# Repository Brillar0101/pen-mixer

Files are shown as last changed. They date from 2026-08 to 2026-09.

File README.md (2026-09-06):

# Pen Mixer

Pen Mixer is a small motion controller that clips onto the top of an ordinary
pen and turns handwriting gestures into live audio control. An IMU on the
board reads tilt and twist, an nRF52840 sends the motion to a laptop over
Bluetooth, and the laptop shapes whatever track is playing: tilt the pen and
a filter sweeps, twist it and the level moves. The better your pen control
gets, the better your mix sounds.

<p align="center">
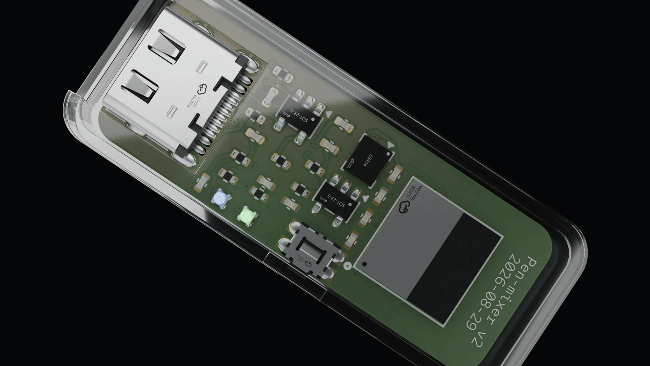
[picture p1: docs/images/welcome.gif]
Pen Mixer v2.1 in its clear case, from five angles
  
</p>

<p align="center"><em>The v2.1 board (13 &times; 35 mm) in its clear case</em></p>

This repo holds the whole project: prototype firmware, production firmware and
laptop stack, and the production PCB as a KiCad project.

```mermaid
flowchart LR
    HAND["Hand<br>tilt, twist"] --> FW

    subgraph pen["Pen Mixer board: on the pen"]
        FW["LSM6DS3TR-C IMU<br>+ ISP1807 nRF52840"]
    end

    FW -->|"BLE, Nordic UART"| BR
    FW -.->|"USB-C, serial"| BR

    subgraph laptop["Laptop"]
        BR["bridge.py<br>smooth, map"] -->|"UDP"| PD["Pure Data<br>filter + gain"]
        BR -->|"SSE"| DASH["dashboard<br>localhost:8080"]
    end

    PD --> SPK["Speakers"]

    classDef pfBlue fill:#E7F1FA,stroke:#0066CC,color:#151515
    classDef pfGold fill:#FDF7E7,stroke:#F0AB00,color:#151515
    classDef pfGreen fill:#F3FAF2,stroke:#3E8635,color:#151515
    classDef pfGray fill:#F0F0F0,stroke:#6A6E73,color:#151515
    class HAND,SPK pfBlue
    class FW pfGreen
    class BR pfGold
    class PD,DASH pfGray
```

## The hardware

Two production board shapes exist. v2.1 is a 13 x 35 mm bar (frozen in
`production/kicad/v2/`). v3, the current design in `production/kicad/`, is a
regular five-point star 40 mm tip to tip with a vertical, top-entry USB-C
(G-Switch GT-USB-7055E) in the body so all five prongs are identical, the
antenna at the top tip, LEDs out on the left arm and the button in the right
arm; otherwise the same parts and the same four-layer 0.8 mm stack. The v2.1 board is a 13 x 35 mm, four-layer, 0.8 mm PCB, all SMD, designed
to ride on a pen barrel with a 401230 LiPo at the back of the pen.

| Ref | Part | Role |
|---|---|---|
| U1 | ISP1807 | nRF52840 with integrated antenna, pre-certified |
| U2 | LSM6DS3TR-C | 6-axis IMU |
| U3 | MCP73831 | LiPo charger, 50 mA |
| U4 | TPS7A02 | 3.3 V LDO, 200 nA quiescent |
| J1 | USB-C 16P | charge, programming, serial |
| J2 | pads on B.Cu | off-board LiPo, 401230 |

The KiCad project lives in `production/`. Schematic PDF, board plots, a render
and the BOM are in `production/output/`.

The board is fully routed and fabrication-ready: 0 unrouted connections,
ground pours on all four layers, and a clean DRC. U1 sits on the official
JLCPCB land pattern with part-for-part verified pad geometry, and every
component carries the 3D model of the exact part being ordered.

Every pinout came from a primary datasheet, kept in `production/datasheets/`.
The one that would have cost a board spin: ISP1807 pin 20 (OUT_ANT) must be
tied to pin 22 (OUT_MOD) on the application PCB, or the radio has no antenna.

## The firmware and laptop stack

`prototype/` runs on the Seeed XIAO nRF52840 Sense today and targets the
custom board unchanged, since both are an nRF52840 with an ST IMU on I2C.

```
prototype/
  bridge.py           serial or BLE, then smoothing, mapping, UDP, dashboard
  ble_source.py       laptop-side BLE client for --ble
  dashboard.py        live web view on :8080
  firmware/
    code.py           IMU over USB serial
    code_ble.py       IMU over BLE, advertises as PenMixer-Lexy
  patches/            Pure Data: track playback, manual sliders, live input
```

How to run all of it, from firmware to Pure Data to the dashboard, lives in
[docs/RUNNING.md](docs/RUNNING.md).

## Run the desktop app

The Qt app in `app/` is the laptop side: it EQs whatever the computer is
playing, driven by the pen over Bluetooth. Full detail, Docker, and
troubleshooting are in `app/README.md`; the short version:

### macOS

```bash
brew install blackhole-2ch switchaudio-osx       # first time only
git clone https://github.com/Brillar0101/pen-mixer.git
cd pen-mixer/app
python3 -m venv venv
venv/bin/pip install -r requirements.txt -e .    # first time only
venv/bin/python -m penmixer.app                  # every time
```

In the window: click "Route system audio here", set Source to "Bluetooth
(pen board)" or use "Scan Bluetooth", play music, move the pen. Closing the
app restores your speakers.

### Windows

First time only, in an administrator PowerShell, then reboot (VB-CABLE is
the Windows loopback device):

```powershell
curl.exe -L -o $env:TEMP\vbcable.zip https://download.vb-audio.com/Download_CABLE/VBCABLE_Driver_Pack45.zip
Expand-Archive $env:TEMP\vbcable.zip $env:TEMP\vbcable -Force
& $env:TEMP\vbcable\VBCABLE_Setup_x64.exe
shutdown /r /t 0
```

Then in a normal PowerShell:

```powershell
git clone https://github.com/Brillar0101/pen-mixer.git
cd pen-mixer\app
python -m venv venv
venv\Scripts\pip install -r requirements.txt -e .   # first time only
venv\Scripts\python -m penmixer.app                 # every time
```

Set Settings > System > Sound > Output to "CABLE Input", then in the window
click "Hear music here", set Source to "Bluetooth (pen board)", play music,
move the pen. Set the output back to your speakers when done.

No board? Set Source to "Simulate (no board)".

## Measured, not estimated

| What | Number |
|---|---|
| Frame rate over USB | 197 Hz against a 250 Hz target |
| Frames in the soak run | 105,872, 0 malformed |
| Smoother settling, alpha 0.4 | 24 ms to 95% of a step |
| End-to-end budget | 32 ms, against ~20 ms where feel degrades |
| BLE vs USB link cost | ~10 ms vs 1 ms |

## Layout

```
prototype/            nRF52840 Sense build: real IMU, USB or BLE, laptop stack
app/                  Qt desktop app: 3-band EQ, visualizer, one-window stack
                      (start instructions for macOS and Windows: app/README.md)
production/           the production board
  kicad/              KiCad 10 project, footprints, 3D models
  datasheets/         primary sources for every pinout
  output/             schematic PDF, board plots, render, BOM, DRC report
docs/                 architecture, run guide, requirements (PRD)
ARCHITECTURE.md       how it all fits together, with diagrams
```

## License

MIT. See [LICENSE](LICENSE).

Built by Barakaeli ([Brillar0101](https://github.com/Brillar0101)) and
Lexy ([vnllagoldfish](https://github.com/vnllagoldfish)).

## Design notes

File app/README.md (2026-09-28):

# Pen Mixer EQ (Qt)

Move a pen, shape the music. This app turns motion from the Pen Mixer board
into a live three-band EQ over whatever the computer is playing: tilt the
pen and the bass swells, roll it and the treble lifts, do both and the mids
come up. A spectrum visualizer and waveform show the sound changing in real
time.

This README explains the whole project from zero: where it came from, how
every piece works, how to run it, and every problem we hit along the way so
you do not have to rediscover them.

## Quick start

Everything below assumes the pen board is already flashed (see
`prototype/flash/README.md`) and advertising as "PenMixer-Lexy".

### macOS

First time only:

```bash
brew install blackhole-2ch switchaudio-osx
git clone https://github.com/Brillar0101/pen-mixer.git
cd pen-mixer/app
python3 -m venv venv
venv/bin/pip install -r requirements.txt -e .
```

Every time:

```bash
cd pen-mixer/app
venv/bin/python -m penmixer.app
```

In the window: click "Route system audio here" (music now flows through the
app), set Source to "Bluetooth (pen board)" or click "Scan Bluetooth" and
pick PenMixer-Lexy, play music, move the pen. Allow the Bluetooth permission
prompt the first time. Closing the app hands your speakers back.

### Windows

First time only (VB-CABLE is the Windows loopback; details in "Running it
on Windows" below):

```powershell
# administrator PowerShell, then reboot
curl.exe -L -o $env:TEMP\vbcable.zip https://download.vb-audio.com/Download_CABLE/VBCABLE_Driver_Pack45.zip
Expand-Archive $env:TEMP\vbcable.zip $env:TEMP\vbcable -Force
& $env:TEMP\vbcable\VBCABLE_Setup_x64.exe
shutdown /r /t 0
```

```powershell
# normal PowerShell, after the reboot
git clone https://github.com/Brillar0101/pen-mixer.git
cd pen-mixer\app
python -m venv venv
venv\Scripts\pip install -r requirements.txt -e .
```

Every time:

```powershell
cd pen-mixer\app
venv\Scripts\python -m penmixer.app
```

Set Windows Settings > System > Sound > Output to "CABLE Input", then in the
window click "Hear music here", set Source to "Bluetooth (pen board)" or use
"Scan Bluetooth", play music, move the pen. Set the Windows output back to
your speakers when you are done.

### No board handy

Set Source to "Simulate (no board)": synthetic pen motion sweeps all three
bands so the whole pipeline demos untethered.

### Spotify now playing, optional

The track card and transport buttons read Spotify's Web API. Without the
setup below the app runs normally with that panel disabled.

1. Create an app at developer.spotify.com/dashboard. Under Redirect URIs
   add exactly `http://127.0.0.1:8888/callback` (Spotify no longer accepts
   `localhost`). Copy the Client ID; there is no secret to keep, the app
   uses PKCE.
2. Put the Client ID in the environment of the shell that launches the app.

   macOS:

   ```bash
   export SPOTIFY_CLIENT_ID=your-client-id
   venv/bin/python -m penmixer.app
   ```

   Windows, this window only:

   ```powershell
   $env:SPOTIFY_CLIENT_ID = "your-client-id"
   venv\Scripts\python -m penmixer.app
   ```

   Windows, permanently (then open a new terminal):

   ```powershell
   setx SPOTIFY_CLIENT_ID "your-client-id"
   ```

3. The first launch opens a browser for the Spotify login. After that the
   token is cached at `~/.cache/penmixer/spotify_token.json` and sign-in is
   silent.

Reading what is playing works on any account; play, pause and skip call
endpoints Spotify limits to Premium. This only feeds the panel and the
buttons: the audio the EQ shapes still has to arrive through BlackHole or
VB-CABLE.

## Where this fits in the bigger project

The parent project is the Pen Mixer: a tiny board (nRF52840 + IMU) that clips
onto a pen and turns handwriting gestures into audio control over Bluetooth.
That hardware lives in this repo (`production/` for the board,
`prototype/firmware/` for the firmware), and its product requirements call
for a three-band EQ mapped to pen motion (bass 60-250 Hz, mid 250 Hz-2 kHz,
treble 2-20 kHz).

During prototyping the board is a Seeed XIAO nRF52840 Sense running the same
firmware. This directory is the laptop side: one Qt app that replaced the
previous three-piece stack (a serial bridge script, a browser dashboard, and
Pure Data patches) with a single window that owns everything. That was a
deliberate requirement: the Qt interface is the only source of truth. Serial
reading, audio processing, and the UI all live in this one process, so what
you see is always what is actually happening.

## How it works, end to end

Follow one pen move through the system:

1. The board runs `code.py` (CircuitPython, in `../prototype/firmware/`).
   Its 6-axis IMU reads tilt and roll from gravity, so 0.0 means the pen is
   level and the ends of the range mean a full lean.

2. Every ~6 ms the firmware prints one line over USB serial:
   `tilt,roll,energy`. Tilt spans -45 to +45 degrees, roll -90 to +90, and
   energy 0 to 1 for overall motion. The BLE firmware emits the same frame
   format over the air, which is the point: everything downstream works
   unchanged whichever link carries it.

3. `serialio.py` runs a Qt thread that auto-discovers the board's port
   (`/dev/cu.usbmodem*`), parses frames (`frames.py`), and reconnects by
   itself if the board is unplugged. A banner at the top of the window shows
   the board state at all times: red "Pen board not detected", green
   "Pen board connected on <port>", amber "simulated input". The banner is
   separate from the audio status line so the two never overwrite each other.

4. `mapping.py` converts a frame to gains, deliberately simple and
   deterministic: tilt scales a bass boost from 0 to +12 dB, roll the same
   for treble, and the mids follow the weaker of the two, so moving both
   ways at once raises the middle. At rest always means flat, 0 dB; the
   music is unchanged until the pen moves. A one-pole smoother tuned to
   ~24 ms (the PRD's F2 figure) keeps the motion glide-smooth.

5. The gains drive three RBJ biquad filters in `eqdsp.py`: a low shelf at
   250 Hz, a peaking filter at 700 Hz (the geometric center of the PRD's mid
   band), and a high shelf at 2 kHz. Filter state persists across blocks;
   coefficients are recomputed only when a gain actually changes, and the
   audio callback ramps toward targets so there are never clicks.

6. `audio.py` owns a duplex sounddevice stream: it reads the system's music
   from the BlackHole loopback device, runs it through the EQ, and writes it
   to the real speakers or headphones. It also applies -9 dB of input
   headroom, because BlackHole delivers system audio hotter than full scale
   (we measured peaks of 1.6) and a +12 dB boost on top of that would clip.

7. `spectrum.py` runs numpy's rfft over the last 2048 output samples and
   produces both three band levels and 32 log-spaced bars (50 Hz to 16 kHz,
   dB scale). `viz.py` draws them cava-style, colored by band, with the raw
   waveform drawn behind. The bars analyze the processed signal, the same
   samples going to your ears, so what you see is real: boost the bass and
   the blue bars rise because the audio itself changed. Only the motion
   styling (fast rise, smooth decay, held peak caps) is cosmetic.

8. `ui.py` is the single source of truth: the window owns the reader, the
   engine, and the gain state. Motion drives the sliders and the sliders
   drive the DSP; untick "Pen control" and you can drag the sliders by
   hand (including cuts). Live meters show the raw tilt and roll input as
   it moves.

## Why BlackHole, and how the routing works

macOS gives no direct way to process another app's audio. The standard
answer is a loopback device: BlackHole 2ch is a virtual audio device that
acts like a cable. Route the system's output into it, and whatever any app
plays lands there as an input this app can read. The chain during a session:

```
YouTube/Spotify -> BlackHole 2ch -> this app (EQ + visualizer) -> speakers
```

Doing that by hand means fiddling with Sound settings, so the app does it
with one click. The "Route system audio here" button (using the
SwitchAudioSource CLI) switches the system output to BlackHole, selects your
real speakers or headphones as the app's output, and starts the engine
immediately, so the music never goes silent, it just changes path. Stopping
the audio or closing the app restores the previous output automatically.
BlackHole itself is excluded from the output choices because selecting it
would create a silent loop.

## Running it

Prerequisites on macOS: `brew install blackhole-2ch` for the loopback and
optionally `brew install switchaudio-osx` for the one-click routing button.

```bash
git clone https://github.com/Brillar0101/pen-mixer.git
cd pen-mixer/app
python3 -m venv venv
venv/bin/pip install -r requirements.txt -e .
venv/bin/python -m penmixer.app
```

Then, in the window:

1. Click "Route system audio here" and play music anywhere
2. Waves and spectrum bars move; you hear the music through the app
3. Set Source to "Bluetooth (pen board)", or click "Scan Bluetooth" and pick
   PenMixer-Lexy; the banner turns green when connected
4. Tilt for bass, sway sideways for mids, twist for treble; each gesture
   boosts one way and cuts the other, and the pen at rest leaves the music flat

No board? Set Source to "Simulate (no board)" and synthetic motion sweeps
the controls so the whole pipeline demos untethered.

## Running it on Windows

The app is cross-platform Python; only the loopback device and the routing
button differ from macOS.

1. Install Python 3.11+ from python.org (tick "Add python.exe to PATH").
   If `python` opens the Microsoft Store instead of running, use `py` in the
   commands below, or reinstall with the PATH box ticked.
2. Install the loopback device: VB-Audio Virtual Cable, the Windows
   equivalent of BlackHole. In an administrator PowerShell (right-click
   Start > Terminal (Admin)):

```powershell
curl.exe -L -o $env:TEMP\vbcable.zip https://download.vb-audio.com/Download_CABLE/VBCABLE_Driver_Pack45.zip
Expand-Archive $env:TEMP\vbcable.zip $env:TEMP\vbcable -Force
& $env:TEMP\vbcable\VBCABLE_Setup_x64.exe    # click "Install Driver"
shutdown /r /t 0                              # reboot is mandatory
```

   If the download URL fails, get it from vb-audio.com/Cable instead:
   extract, right-click `VBCABLE_Setup_x64.exe`, Run as administrator,
   Install Driver, reboot. After the reboot, verify the cable exists:

```powershell
venv\Scripts\python -c "import sounddevice; print(sounddevice.query_devices())"
```

   The list must show "CABLE Input (VB-Audio Virtual Cable)" and "CABLE
   Output (VB-Audio Virtual Cable)". No CABLE devices means the install or
   the reboot did not happen. If they are in the list but not in the app,
   click the app's Rescan button.
3. Clone and set up (run from the project root, and keep the trailing dot
   on the install command; it means "this folder" and installs the app):

```powershell
git clone https://github.com/Brillar0101/pen-mixer.git
cd pen-mixer\app
python -m venv venv
venv\Scripts\pip install -r requirements.txt -e .
venv\Scripts\python -m penmixer.app
```

4. Route the audio by hand (the route button is macOS-only, it uses a
   macOS tool): Settings > System > Sound > Output > "CABLE Input
   (VB-Audio Virtual Cable)". Then click "Hear music here" in the app: it
   selects CABLE Output as input, your speakers as output, and starts the
   audio, trying several sample rates until the stream opens. The music
   becomes audible through the app, with the EQ live on it.
5. Plug in the board. Windows names serial ports COM3-style and the app
   accepts any COM port that reports a USB vendor id, so detection works
   the same; the banner turns green.

Remember to switch the system output back to your speakers when done;
on Windows the app cannot restore it for you.

Do not use "Stereo Mix" as the input even though it looks like a loopback:
it taps the same speakers this app plays into, so the app would hear its
own output and feed back on itself, and many Realtek drivers mix the
microphone into it as well.

## Spotify now playing

The track card (artwork, title, artist, progress) and the transport buttons
talk to the Spotify Web API. This is separate from the audio path: the API
tells the app what is playing, while the sound itself still has to reach the
EQ through the loopback device. Fixing one does not fix the other, and the
EQ works fine with Spotify never configured at all.

Auth is PKCE, so there is no client secret to keep safe, but you do need a
client id of your own. It is not a secret and it is safe to paste into a
shell.

1. Go to https://developer.spotify.com/dashboard and create an app. Any name
   works.
2. In the app's settings, add `http://127.0.0.1:8888/callback` as a redirect
   URI. It has to match exactly, including the port. If you want a different
   one, set `SPOTIFY_REDIRECT_URI` to match.
3. Copy the Client ID.
4. Set it in the environment before launching. It is read once at import, so
   exporting it after the app starts does nothing.

```powershell
# Windows
$env:SPOTIFY_CLIENT_ID="paste-your-client-id-here"
venv\Scripts\python -m penmixer.app
```

```bash
# macOS and Linux
export SPOTIFY_CLIENT_ID=paste-your-client-id-here
venv/bin/python -m penmixer.app
```

The first run opens a browser to sign in, then caches the refresh token at
`~/.cache/penmixer/spotify_token.json` so later runs skip that step. The
cache holds only the tokens, not the client id, so you still need the
environment variable every time. Setting it permanently (a shell profile, or
System Properties on Windows) saves rediscovering it later.

Without the variable the track card reads "Set SPOTIFY_CLIENT_ID" and the
transport buttons are disabled. That is the expected state, not a failure to
connect.

## Installing Docker

Docker is optional: the app runs natively without it. It gives you the
reproducible test suite anywhere, and the containerized app path.

macOS:

```bash
brew install --cask docker    # or download Docker Desktop from docker.com
open -a Docker                # first start; wait for the whale icon
docker --version              # verify
```

Windows: install Docker Desktop from docker.com/products/docker-desktop.
It requires the WSL2 backend; the installer sets it up (or run
`wsl --install` in an elevated PowerShell first, then reboot). Verify with
`docker --version` in PowerShell. The `docker compose run --rm test` suite
works identically; the containerized GUI app path is documented for macOS
and untested on Windows (WSLg can display it, but the audio and serial
bridges are macOS scripts).

Linux: `curl -fsSL https://get.docker.com | sh`, then log out and in after
adding yourself to the docker group (`sudo usermod -aG docker $USER`).

## The nRF52840 pen board over Bluetooth

The app talks to the pen board directly: set the Source dropdown to
"Bluetooth (pen board)" or click "Scan Bluetooth" to pick it from a list of
everything in range. The board runs the firmware in `prototype/flash`
(flash kit with CircuitPython, libraries and `code.py`); it advertises as
"PenMixer-Lexy" with a Nordic UART service. The app scans, connects, and
reconnects on its own; the banner reports every state. On macOS the first
scan pops a Bluetooth permission prompt for the terminal or Python; allow
it or the scan finds nothing.

The mapping is signed around the pen at rest, so holding still is flat
(0 dB) and every band moves both ways:

| Gesture | Band | Direction |
|---|---|---|
| Tilt forward / back | Bass 60-250 Hz | forward boosts to +12 dB, back cuts to -12 dB |
| Sway left / right (horizontal stroke) | Mid 250 Hz-2 kHz | right boosts, left cuts (PRD M2) |
| Twist | Treble 2-20 kHz | one way boosts, the other cuts |

Sway comes from the firmware as a fourth frame value: a leaky integral of
the gyro rate about the sweep axis, so a stroke builds the value and
holding still lets it drift back to center. Older three-field firmware still
works; sway simply reads zero. If the "Sway (mid)" meter reacts to the
wrong gesture for how the board sits on the pen, change `SWAY_AXIS` in the
firmware (0, 1 or 2) and copy `code.py` back onto CIRCUITPY.

## Tests and Docker

Every module without Qt or hardware dependencies (frames, mapping, eqdsp,
spectrum) has a pytest suite: parsing and clamping, the mapping rules, the
measured filter response (a +12 dB bass boost must raise a 100 Hz tone by
more than 9 dB while moving an 8 kHz tone by less than 1 dB), and FFT band
assignment. Run natively:

```bash
venv/bin/python -m pytest
venv/bin/ruff check src tests
```

Or in Docker, which needs no audio, no USB, and no macOS:

```bash
docker compose run --rm test
```

The app itself can also run inside Docker (`docker compose up --build app`),
which on macOS needs three host bridges because containers cannot reach the
display, CoreAudio, or USB: XQuartz for the window, PulseAudio for sound,
and a socat serial-to-TCP forward. `scripts/host_bridges.sh` sets those up.
It works, but the network audio hops add latency, so for a live music demo
run natively and treat the containerized app as the portability proof.

## Requirements traceability

The PRD lives in this repo (`../docs/PRD.md`). Where this app stands:

| Req | Requirement | This rig |
|-----|---|---|
| F1  | Some form of feedback | Met: live audio change, spectrum bars, dB readouts, pad meters |
| F2  | Continuous control, 24 ms smoothing | Met: smoothing tuned to ~24 ms plus a click-free gain ramp |
| F3  | Deterministic, repeatable mapping | Met: pure function of frame values; same gesture, same sound |
| F4  | Bluetooth link to the laptop | Met: BLE to the nRF52840 board, with USB serial as the wired fallback |
| M1  | Bass 60-250 Hz | Met: tilt drives the bass band |
| M2  | Mid 250 Hz-2 kHz, left cuts / right boosts | Partial: the USB path boosts only; over Bluetooth the gains are signed so cuts work, and the mids stay slider-only until the firmware streams a third axis |
| M3  | Treble 2-20 kHz | Met: roll drives the treble band |
| P1-P7, Q1-Q2, I1-I3 | Physical, NFC, interface | Out of scope: board hardware, not this laptop rig |

## Problems we hit, so you do not have to

Real issues from building and demoing this, with their fixes:

- "No module named penmixer" when launching: the package lives under `src/`
  and must be installed into the venv (`pip install -e .`). The tests passed
  anyway because pytest adds the path itself, which hid the problem.
- Silent app, music still audible: the system output was never routed to
  BlackHole, so the app was analyzing silence while the browser played to
  the speakers. The app now detects two seconds of silent input while
  running and says exactly what to fix in the status line.
- Silent everything after routing: the system output was left on BlackHole
  by an earlier session and the route button's "already routed" branch did
  nothing. It now recovers: picks real speakers, starts the engine, and
  remembers a restore target so closing the app never strands the system
  on BlackHole.
- Routed, engine running, still silent: the music itself had stopped, or
  the browser tab was still bound to the old audio device. Reloading the
  tab and pressing play fixes it; browsers follow the default device but
  sometimes only after a reload.
- Distortion risk on boosts: BlackHole delivers hotter-than-full-scale
  audio, so the engine takes -9 dB of input headroom before the EQ.
- Bluetooth headphones add latency, so the EQ response trails the pen motion
  slightly; wired output feels snappier for a live demo.
- Charge-only USB-C cables are the classic reason the board banner stays
  red with the board plugged in. Bring a known data cable.

## Repo layout

```
src/penmixer/
  frames.py     parse "tilt,roll,energy" serial frames
  mapping.py    motion -> band gains, deterministic, PRD-tuned smoothing
  eqdsp.py      RBJ biquads, stateful 3-band EQ      (no Qt: tested in Docker)
  spectrum.py   rfft band levels + log spectrum bars (no Qt: tested in Docker)
  audio.py      duplex stream, gain ramping, input headroom
  serialio.py   USB serial reader, auto-discovery, reconnect, board banner
  tcpio.py      same frames over TCP, for the Docker serial bridge
  routing.py    one-click system output switching via SwitchAudioSource
  viz.py        spectrum bars + waveform widget
  ui.py         main window: the single source of truth
  app.py        entry point
tests/          pytest suite for every no-Qt module
scripts/        host_bridges.sh for the Docker app path
```

## What comes next

The natural next steps, in rough order: signed mid control once the
firmware streams a third axis (closes M2), and profiles for different
mappings (which band each gesture drives, boost ranges, cut support).

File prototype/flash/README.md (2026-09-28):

# Flashing the pen board

Everything needed to take a Seeed XIAO nRF52840 Sense from blank to
streaming pen motion. The steps are the same on macOS and Windows: the
board shows up as a plain USB drive (Finder on macOS, File Explorer on
Windows) and flashing is copying files onto it. This folder holds:

- `circuitpython-xiao-sense.uf2`: the CircuitPython runtime for the board
- `code.py`: the BLE firmware, ready to copy (a copy of
  `../firmware/code_ble.py`)
- `lib/`: the libraries the firmware imports

## Fresh board, or reinstalling CircuitPython

1. Plug the board in over USB-C. Use a known data cable; a charge-only
   cable is the classic reason nothing shows up.
2. Double-tap the small reset button beside the USB connector, two quick
   presses like a double-click. A drive named `XIAO-SENSE` appears in
   Finder or File Explorer.
3. Drag `circuitpython-xiao-sense.uf2` onto that drive. The board reboots
   by itself and the drive comes back as `CIRCUITPY`.
4. Copy `code.py` and the whole `lib/` folder onto `CIRCUITPY`. Wait for
   the copy to finish, then eject the drive (macOS: drag to the eject
   icon; Windows: "Safely Remove Hardware") before unplugging.

The firmware starts the moment the copy lands. This `code.py` is the BLE
build: the board advertises as `PenMixer-Lexy`, and the app's Scan Bluetooth
button or a green "Pen board connected" banner confirms it is alive.

## The rest pose, and why the grip matters

This build zeroes itself against however you happen to be holding the pen.
For the first half second after the app connects it averages the sensors,
and that pose becomes flat: tilt reads zero there, and the gyro bias it
measures in the same window is subtracted from every later frame. So hold
the pen in your normal writing grip, still, while the app connects. Waving
it around during that window bakes a bad zero into the whole session, and
the only way out is to disconnect and reconnect.

Two of the three gestures are integrated from the gyro rather than measured
against gravity, because with the pen upright a twist rotates around gravity
itself and the accelerometer cannot see it at all. Integrated values cannot
hold forever, so they ease back toward flat on a six second time constant
(`SWAY_TAU` and `TWIST_TAU`). Shorten those if you want the bands to recentre
on their own sooner, lengthen them if a held pose slips away too fast. Only
tilt is absolute.

## Updating the firmware only

CircuitPython is already on the board, so skip the uf2: plug in, wait for
`CIRCUITPY` to mount, and replace `code.py` on the drive. The board
restarts the code automatically on every save.

## Choosing USB serial instead of Bluetooth

CircuitPython runs whatever file is named `code.py` on the drive. For the
wired build, copy `../firmware/code.py` onto `CIRCUITPY` instead; for
Bluetooth, use this folder's `code.py` (which is `../firmware/code_ble.py`).
The laptop side is the same either way, only the Source setting changes.

## Renaming the board

The advertised name is one line in the firmware, `ble.name = "PenMixer-Lexy"`.
Change it before copying, and change the matching name on the laptop side
(`DEVICE_NAME` in `app/src/penmixer/bleio.py`, and `ble_source.py` for the
prototype bridge). macOS caches Bluetooth names, so the old one can linger
in scans for a while after a rename.

## If something looks wrong

- No `XIAO-SENSE` drive after the double-tap: retime the two presses, and
  swap in a data cable.
- Board runs but no motion: open a serial console to read the error.
  macOS: `screen /dev/cu.usbmodem* 115200`. Windows: find the COM port in
  Device Manager, then PuTTY at 115200 baud, or
  `py -m serial.tools.miniterm COM5 115200` if pyserial is installed.
  Also check that `lib/` actually copied over; missing libraries fail on
  the first import.
- BLE build not found in a scan: a connected board stops advertising, so
  disconnect the app first, or power-cycle the pen.

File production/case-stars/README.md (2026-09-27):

# Slab case (stars removed)

Snap-fit enclosure for the prototype rig, based on the 59 x 25 x 15 mm
snap-fit case (`~/Documents/snap-fit-case-59x25x15-openings`), with slide
rails on top for a 58 x 27 x 5 mm wooden slab. The star cut-outs were
removed; set `stars` in enclosure.scad to bring them back.

- `enclosure.scad`: the source. Stars, rails and slab size are parameters
  near the top. Export with `openscad -D 'part="top"' -o top.stl` (and
  `bottom`, `assembled`, `exploded`, `layout`).
- `bottom.stl`, `top.stl`: print orientation, both at Z = 0. The slab rails
  are part of the lid.
- `stars.3mf`: PrusaSlicer project, both parts side by side on the
  Anycubic Mega S bed with the transparent-PLA settings.
- `stars.gcode`: ready to print on the Mega S. 3 h 52 min, 21.7 g PLA.
- `case_both.blend`: assembled scene with the slab in the rails.
- `tools/make_3mf.py`, `tools/make_blend.py`: rebuild the 3MF and the
  Blender scene after re-exporting the STLs.
- `megas_pla_prusaslicer.ini`: the base Mega S PLA profile.

## Print settings (transparent PLA)

0.12 mm layers, 5 perimeters, 100% rectilinear infill, 12 top and bottom
layers with monotonic fill, 215 C, 20 mm/s outer walls, aligned seam,
supports in the slab channel only. The solid fill keeps the part evenly translucent; the fine layers
keep edges crisp.

## Notes

- Cavity 59 x 25 x 15 mm. Lid snaps over the tray with four hooked tabs.
- The slab slides in from the -X end and stops against the +X wall; a
  0.3 mm detent under each lip holds it. Channel is 29.3 x 6.3 mm for a
  27 x 5 mm slab (1.15 mm per side, 1.3 mm above), widened after the first
  slab did not fit. Lips reach 2.5 mm in, overlapping the slab 1.35 mm.
- Rail and stop-wall edges are rounded at 0.45 mm.
- The lid prints rails-down, so its roof spans the 27.3 mm slab channel.
  Printing that as an unsupported bridge failed, so the slice puts support
  material inside the channel only (build plate only, 0.2 mm gap, 2
  interface layers). Pull it out through the open entry end; the marks sit
  on the roof face the slab covers.
- 5 mm brim and 65 C bed (70 C first layer) for adhesion. Clean the plate
  with IPA or soap and water first.

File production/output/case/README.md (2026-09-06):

# Case print files

Two clear shells exported from `production/blender/pen-mixer.blend` in
millimetres, ready to upload for 3D printing (PRD P2).

| File | Size (mm) | Holds |
|---|---|---|
| `case_bottom.stl` | 15.40 x 39.60 x 6.05 | board and battery, USB-C notch |
| `case_top.stl` | 15.40 x 39.59 x 2.35 | covers the components, slot for the side button |

Order notes (from the PRD): JLCPCB 3D printing, 8001 clear resin, no
supports needed for either half, print with the open face down. The halves
hold by wall friction plus the USB-C notch keying them together; if the
printed fit is loose, snap ridges are the fallback. The LEDs shine through
the clear resin. Not yet printed; ordering closes P2.

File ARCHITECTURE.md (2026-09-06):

# Architecture: Pen Mixer on the XIAO nRF52840 Sense

## Context

Pen Mixer is a pen-mounted motion controller. Tilt the pen and a filter sweeps
across whatever track is playing on the laptop; twist it and the level moves.
This repo is the product build: the Sense board carries a 6-axis IMU and
Bluetooth on one 21 x 17.5 mm board, so real pen movement drives the audio.

Numbers in this document are measured on the working rig, not estimated.
Where something is estimated or unverified it says so.

## Components

| Component | Responsibility | Where it runs |
|---|---|---|
| LSM6DS3TR-C | 6-axis IMU, tilt and roll from gravity | on the board, I2C 0x6A |
| `code.py` | reads the IMU, emits CSV frames | CircuitPython on the board |
| `bridge.py` | parse, smooth, map, fan out | laptop, stdlib only |
| Pure Data | applies filter and gain to the playing track | laptop |
| `dashboard.py` | live view of every channel | laptop, port 8080 |

The frame format is the contract between firmware and everything else:

```
tilt,roll,energy
14.44,88.63,0.146
```

Both firmwares emit it, which is why the laptop side never changes between
USB and BLE.

## Signal topology

```mermaid
flowchart LR
    HAND["Hand<br>tilt, twist"] --> IMU

    subgraph pen["XIAO nRF52840 Sense: on the pen"]
        IMU["LSM6DS3TR-C<br>I2C 0x6A"] -->|"IMU_PWR high,<br>then 250 Hz reads"| FW["code.py<br>tilt/roll from gravity"]
    end

    FW -->|"USB serial CSV<br>197 Hz measured"| BR
    FW -.->|"BLE, Nordic UART<br>~10 ms, code_ble.py"| BR

    subgraph laptop["Laptop"]
        BR["bridge.py<br>smooth alpha 0.4, map"] -->|"UDP FUDI<br>cutoff 4820.1153;"| PD["Pure Data<br>lop~, *~, 128 buf"]
        BR -->|"SSE"| DASH["dashboard<br>localhost:8080"]
        BR -.->|"malformed frame"| BAD["discard, bad++"]
    end

    PD --> SPK["Speakers"]

    classDef pfBlue fill:#E7F1FA,stroke:#0066CC,color:#151515
    classDef pfGold fill:#FDF7E7,stroke:#F0AB00,color:#151515
    classDef pfGreen fill:#F3FAF2,stroke:#3E8635,color:#151515
    classDef pfGray fill:#F0F0F0,stroke:#6A6E73,color:#151515
    classDef pfRed fill:#FAEAE8,stroke:#C9190B,color:#151515
    class HAND pfBlue
    class IMU,FW pfGreen
    class BR pfGold
    class PD,DASH pfGray
    class BAD pfRed
    class SPK pfBlue
```

The bridge is the gold box because it holds all the tuning: the smoother, the
mapping, and both outputs. Malformed frames take the red edge, get discarded,
and increment a counter the dashboard shows. If `bad` climbs, something
upstream broke.

The measured 197 Hz against a 250 Hz target is USB scheduling plus
CircuitPython's `print()` overhead. It has not caused problems.

## Latency budget

```mermaid
flowchart LR
    S["sensor read<br>4 ms"] --> U["USB<br>1 ms"] --> SM["smoother, alpha 0.4<br>24 ms"] --> B["audio buffer<br>3 ms"] --> OUT["32 ms total"]

    classDef pfGreen fill:#F3FAF2,stroke:#3E8635,color:#151515
    classDef pfGold fill:#FDF7E7,stroke:#F0AB00,color:#151515
    classDef pfGray fill:#F0F0F0,stroke:#6A6E73,color:#151515
    class S,U,B pfGreen
    class SM pfGold
    class OUT pfGray
```

Past roughly 20 ms end to end, the connection between moving your hand and
hearing the change breaks and it stops feeling like an instrument. Smoothing
is the gold box because it eats 24 of the 32 ms and it is the only term you
can change freely. Measured settling to 95% of a step at 250 Hz:

| alpha | settles in | feel |
|---|---|---|
| 0.05 | 236 ms | unusable |
| 0.15 | 76 ms | visibly behind your hand |
| 0.4 | 24 ms | the default |
| 0.5 | 20 ms | snappier, more jitter through |
| 1.0 | 0 ms | raw, audible clicks on the filter |

A one-pole filter picks one setting for both fast and slow motion. A one-euro
filter adapts, and that is the right upgrade once the mapping stops changing.

## Mapping

| Gesture | From | Drives | Curve |
|---|---|---|---|
| Tilt forward and back | accelerometer pitch | filter cutoff, 80 Hz to 12 kHz | exponential |
| Twist the barrel | accelerometer roll | gain, 0.25x to 1.75x | linear |
| Move fast | acceleration magnitude | effect send, 0 to 1 | linear |

Frequency is perceived logarithmically, so the cutoff mapping is exponential.
A linear sweep spends most of its travel where the ear barely registers it.

Tilt and roll come from the gravity vector, so they are absolute and do not
drift. There is no sensor fusion to write.

## Production board

The custom PCB is a separate KiCad project: 13 x 35 mm, four layers, 0.8 mm,
all SMD.

```mermaid
flowchart LR
    USB["USB-C<br>J1, 5 V"] --> CHG["MCP73831<br>U3, charger 50 mA"]
    USB --> MOD
    CHG --> BAT[("LiPo 401230<br>off-board, J2 on B.Cu")]
    BAT -->|"3.0 to 4.2 V"| LDO["TPS7A02<br>U4, 3.3 V LDO"]
    LDO -->|"3.3 V"| MOD["ISP1807<br>U1, nRF52840 + antenna"]
    LDO -->|"3.3 V"| SNS["LSM6DS3TR-C<br>U2, 6-axis IMU"]
    SNS -->|"I2C 0x6A, SA0 low"| MOD
    MOD --- KO["antenna keep-out<br>all 4 layers"]

    classDef pfBlue fill:#E7F1FA,stroke:#0066CC,color:#151515
    classDef pfGold fill:#FDF7E7,stroke:#F0AB00,color:#151515
    classDef pfGreen fill:#F3FAF2,stroke:#3E8635,color:#151515
    classDef pfGray fill:#F0F0F0,stroke:#6A6E73,color:#151515
    classDef pfRed fill:#FAEAE8,stroke:#C9190B,color:#151515
    class USB pfBlue
    class CHG,LDO,SNS pfGray
    class BAT pfGold
    class MOD pfGreen
    class KO pfRed
```

The cell cannot feed the module directly: it runs to 4.2 V and the module's
ceiling is 3.6 V, so power returns through the LDO. The keep-out is red
because it is the constraint that decides the board's shape: no copper on any
layer at that end, or the antenna detunes and range collapses.

## Key decisions

### The ISP1807 module, not a bare nRF52840

The module carries the radio, matching network and antenna, plus modular
FCC/CE certification the host product inherits. A bare chip means owning RF
matching, antenna design and certification testing, which runs to five
figures. One wiring detail worth its own sentence: pin 20 (OUT_ANT) must be
tied to pin 22 (OUT_MOD) on the application PCB, or the radio has no antenna.

The ISP1807 land pattern is JLCPCB's official one (their EasyEDA library),
swapped in after a pad-for-pad comparison confirmed it matches the vendor
geometry exactly: all 78 pads, same numbering, same sizes, same positions.

### FUDI over UDP, not OSC

Pd's `netreceive` parses plain text natively, so there are no OSC externals
to install and the bridge stays stdlib-only. The cost is that nothing
validates message names; a typo in the patch fails silently.

### Local WAV for demos, BlackHole for live audio

The Spotify API never exposes the raw audio stream, and the Web Playback SDK
runs in a protected context you cannot tap for DSP. Demos that must not fail
use `readsf~` on a local WAV. Live audio routes Spotify's output through a
virtual driver (BlackHole) into Pd, which matches what the finished product
does. BlackHole needs `sudo killall coreaudiod` after install before
CoreAudio will list it.

### X/Y position is out of scope

Position on the page needs an optical sensor held at a fixed height and angle
to the paper. A hand-held pen changes both constantly, which makes the mount
the hard engineering problem. Tilt, twist and motion energy give four usable
channels without it.

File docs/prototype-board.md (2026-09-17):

# Pen Mixer prototype board

The full-prototype rig: a Seeed XIAO nRF52840 Sense riding on an ordinary
pen, running the firmware in `../prototype/firmware/` unchanged. No custom
PCB. This is the build for working sessions before (or instead of) fabbing
the production board.

## Bill of materials

Core, about $26 if starting from nothing:

| Item | Part | Qty | Cost |
|---|---|---|---|
| Motion board | Seeed XIAO nRF52840 Sense | 1 | $16 |
| Pen | any ballpoint, thicker barrel | 1 | $2 |
| USB-C cable | data-capable, not charge-only | 1 | $8 |

Wireless additions, about $8 (sourced from Adafruit, chosen for minimum
bulk on the pen):

| Item | Part | Qty | Cost |
|---|---|---|---|
| LiPo cell | Adafruit 1570, 3.7 V 100 mAh, JST-PH, protected, 11.5 x 31 x 3.8 mm, 3 g | 1 | $5.95 |
| Battery pigtail | Adafruit 1131, JST-PH extension cable; cut the plug end, solder to BAT pads | 1 | $1.95 |

There is no power switch: unplugging the cell from the pigtail is the off
switch. The switched breakout (Adafruit 1863) was rejected as too tall for
the pen, and the inline switched cable (Adafruit 3064) was out of stock.
100 mAh clears the PRD's 3 hour target on the measured ~6 mA average BLE
draw. The 401230 bare cell in the production BOM is for the custom board
only; the prototype wants a protected JST-PH cell, since the XIAO's charger
is the only battery management in the loop.

## Battery wiring

The XIAO powers itself from the cell and charges it over USB. Cut the plug
end off the extension cable and solder its wires to the two BAT pads on the
underside; the cell then clicks into the socket end, unmodified:

    cell -> JST socket ... red  -> BAT+
                           black -> BAT-

- Polarity is unforgiving; check twice before soldering.
- Cut the cable one wire at a time so the bare leads never touch.
- BAT pads only, never the 3V3 pin; 3V3 bypasses the regulator.
- Unplugging the cell is the power switch; the XIAO has none of its own.
- Trim the cable short; 500 mm is far more than a pen needs.
- Charging is 50 mA from the onboard BQ25101, fine for a 100 mAh cell.

Battery operation is proven (BLE streaming at ~67 fps on the cell); runtime
against the PRD's 3 hour target is not yet measured. Rerun
`../prototype/tools/battery_soak.py` with USB unplugged until the cell runs
down; it writes the verdict to `measurements/battery-soak.md`.

## Mounting rules

- Nothing conductive against the back of the board: the castellated pads and
  BAT pads are exposed, and bare metal across them shorts it.
- Keep metal away from the USB-C end; the antenna is there, and metal beside
  it kills BLE range.
- Leave the BAT pads uncovered if the cell might come later.
- USB-C port faces the back of the pen so the cable runs away from the hand.

## What it does

| Gesture | Drives |
|---|---|
| Tilt forward/back | Filter cutoff, 80 Hz to 12 kHz |
| Twist the barrel | Low-shelf gain, +/-15 dB |
| Scribble fast/slow | Reverb or delay send |
| Tap the pen down | Freeze / unfreeze |

X/Y position on the page is out of scope: it needs an optical sensor held at
a fixed height and angle to the paper, which is the hard mechanical problem.

## Software

Flashing, from a blank board up: [../prototype/flash/README.md](../prototype/flash/README.md).
Running the stack, bridge to dashboard: [RUNNING.md](RUNNING.md).
The desktop app lives in `../app/`.

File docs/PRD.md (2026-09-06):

# Product requirements document

Requirements for the Mixer Pen, taken from the client brief and the academic
rubric. Each one is marked with where it stands: **v1** means it works today,
**v2** means it is planned for the second version. Nothing here is quietly
dropped; if v1 misses a requirement, the table says so.

## Functional requirements

| # | Requirement | Status |
|---|---|---|
| F1 | Some form of feedback | **Done.** The audio itself changes live, and the Qt app (app/) shows a live spectrum, the waveform, dB readouts per band, and pad/motion meters as you move. |
| F2 | Manipulate sound and get better at it | **Done.** Continuous control with 24 ms smoothing in the app plus a click-free gain ramp in the audio path, so small hand improvements are audible. |
| F3 | Gesture rewards practice | **Done.** The mapping is a pure function of the motion frame (app/src/penmixer/mapping.py); a practiced gesture lands the same gains every time. |
| F4 | Bluetooth link to the laptop, controlling the audio player | **Done.** BLE (Nordic UART) straight into the Qt app, which applies the EQ to whatever the laptop is playing. The app scans, lists devices, connects, and reconnects on its own; the bridge.py and Pure Data path is retired. |

## Pen direction mapping

The brief asks for a three-band EQ mapped to pen motion. The Qt app
implements the three-band EQ (bass 60-250 Hz, mid 250 Hz-2 kHz, treble
2-20 kHz) and drives all three bands from the pen, signed, so motion one
way boosts and the other way cuts: tilt for bass, horizontal sway for mids,
twist for treble.

What each gesture means:

- Tilt: leaning the pen forward and backwards.
- Sway: moving the pen left and right, like a horizontal stroke.
- Twist: rotating the pen around its own long axis, so the pen's
  orientation itself changes, up to a full 360.

| # | Requirement | Status |
|---|---|---|
| M1 | Bass 60-250 Hz on vertical motion (y), like writing an "l" | **Done in app.** Pen tilt drives the bass band, signed: forward boosts to +12 dB, back cuts to -12 dB. Tilt orientation stands in for vertical motion. |
| M2 | Mids 250 Hz-2 kHz on horizontal motion (x), like crossing a "t"; left cuts, right boosts | **Done in app and firmware.** The firmware streams a fourth value, sway, a leaky integral of the gyro rate about the sweep axis; a stroke right boosts the mids, left cuts, holding still drifts back to flat. The sweep axis is a one-line constant (SWAY_AXIS) to match how the board sits on the pen. |
| M3 | Treble 2-20 kHz on orientation, upright (90&deg;) as base; leaning toward 0&deg; adds brightness | **Done in app.** Pen twist (roll) drives the treble band, signed, both directions. |

## Physical requirements

| # | Requirement | Status |
|---|---|---|
| P1 | At most 30 mm in both directions | **v3 diverges by design: the client asked for a regular star-shaped board, 40 mm tip to tip, with a vertical USB-C in the body.** v2 history: **Improved in v2.** v1 was 11 x 42 mm; v2 is 13 x 35 mm, 0.8 mm thick (JLCPCB's 4-layer minimum; 0.6 was the original target); the battery wires solder to pads at the tip and the cell lies along the back. Still 5 mm over the 30 mm limit lengthwise; getting under it means dropping USB-C for charge pads. |
| P2 | Clear casing | **Designed for v2.1; v3 needs a new shell** (star outline, opening in the top for the vertical USB-C). v2.1 shell: **Designed.** Two clear shells, about 15.4 x 39.6 mm: bottom holds board and battery, top covers the components, with a USB-C opening and a slot for the side button; the LEDs shine through. The USB-C sits in an open notch, fully exposed and standing 0.7 mm proud of the case; the roof is only as tall as the side button needs (9.25 mm total; 1 mm walls). No screws: the halves hold by wall friction and the USB notch keying them together; snap ridges are the fallback if the printed fit is loose. Print in clear resin (JLCPCB 3D printing, 8001 resin). Not yet fabricated. |
| P3 | Weight at most 1 oz (28 g) | **v1 by design.** Board plus battery is roughly 5 g. Stays met with any reasonable casing; final weight gets measured in v2 with the shell on. |
| P4 | Runs 3 hours at once | **v1 by design.** The 100 mAh cell against a ~6 mA average BLE draw estimates well past 3 h. Estimated, not yet measured; a soak test is on the v2 checklist. |
| P5 | Attaches to the top of a pen, semi-universal, ~3 mm of adjustment | **v2.** v1 mounts with a hose clamp for bench testing. v2 gets a sprung or rubber-lined clip sized for a mechanical pencil, a number 2 pencil, and a Bic. |
| P6 | On and off with one hand, rubber for grip | **v2.** Part of the same clip design as P5. |
| P7 | Position near the top, on top or beside it | **v1.** The mount already targets the top of the pen; the mapping does not care which side. |

## Open questions from the brief

| # | Question | Answer |
|---|---|---|
| Q1 | Can we include an NFC chip? | **v2, and cheaply, with one routing note.** The nRF52840 inside the ISP1807 has an NFC-A tag peripheral built in; the module exposes the NFC1/NFC2 pins. v2 adds only a small antenna coil and a tuning capacitor. The IMU interrupt lines were disconnected from P0.09/P0.10 (the NFC1/NFC2 pins) so the antenna can use them; the firmware polls the IMU and never needed the interrupts. |
| Q2 | Song requests over NFC, e.g. pass a YouTube link to the chip | **v2.** The tag can carry an NDEF record with a URL that a phone tap reads, and the laptop bridge can rewrite it over BLE. Fetching audio from YouTube itself stays on the laptop side and depends on the source being licensed. |

## Interface requirements, added after v2

New requirements from the client. None of this exists in the v2 hardware,
which has one green LED (charge status) and no button; all three need the
v2.1 board revision plus firmware.

| # | Requirement | Status |
|---|---|---|
| I1 | Battery level indicator on an LED with four states: red, orange, green, white | **In the v2.1 board; firmware written, untested.** LED1, a 1 x 1 mm addressable RGB (XL-1010RGBC); white is all three channels on. Thresholds: red below 10%, orange 10-40%, green 40-80%, white above 80%, from VBAT_SENSE (P0.03, 1M/1M divider). production/firmware/code.py implements it; verification waits on the assembled v2.1 board. |
| I2 | Power button: press to turn on, press to turn off, long press to start Bluetooth pairing | **In the v2.1 board; firmware written, untested.** SW1 on wake-capable P0.17. production/firmware/code.py: short press enters System OFF deep sleep with a pin alarm on the button to wake, long press (1.5 s) restarts advertising. Verification waits on the assembled board. |
| I3 | Bluetooth status LED: a fixed color when connected, flashing when pairing is ready | **In the v2.1 board; firmware written, untested.** LED2 chained after LED1 on P0.20. production/firmware/code.py: blue flashing while advertising, solid blue when connected, back to flashing if the link drops. Verification waits on the assembled board. |

Hardware as built in v2.1: two 1 x 1 mm addressable RGB LEDs (chained, one
GPIO, no resistors), one side-actuated tactile switch, one decoupling cap;
two GPIO lines total (P0.20 data, P0.17 button).

## What comes next, in one list

Assemble the v2.1 board and verify its interface firmware on it (I1-I3),
the 30 mm board (P1), the clear casing fabricated and fitted (P2), the
one-handed adjustable clip (P5, P6), the NFC antenna and song-request flow
(Q1, Q2), and measured
numbers for weight and battery life (P3, P4).

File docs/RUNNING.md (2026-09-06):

# Running Pen Mixer

The laptop side is the Qt desktop app in `app/`: it EQs whatever the computer
is playing, driven by the pen over Bluetooth, with a live spectrum so you can
see the sound change. The board is a Seeed XIAO nRF52840 Sense (the same
firmware targets the production board unchanged), flashed once from
`prototype/flash/`; it advertises as `PenMixer-Lexy`.

## 1. Flash the board (once)

Copy `prototype/flash/code.py` and `prototype/flash/lib/` onto the board's
CIRCUITPY drive. Full steps from a blank board, for macOS and Windows, are in
[prototype/flash/README.md](../prototype/flash/README.md). Unplug the board
afterward and it runs on its battery.

## 2. Start the app on macOS

First time only:

```bash
brew install blackhole-2ch switchaudio-osx
git clone https://github.com/Brillar0101/pen-mixer.git
cd pen-mixer/app
python3 -m venv venv
venv/bin/pip install -r requirements.txt -e .
```

Every time:

```bash
cd pen-mixer/app
venv/bin/python -m penmixer.app
```

In the window:

1. Click "Route system audio here". The music now flows through the app and
   keeps playing; the waves and spectrum bars move.
2. Set Source to "Bluetooth (pen board)", or click "Scan Bluetooth" and pick
   `PenMixer-Lexy`. Allow the Bluetooth permission prompt the first time.
   The banner turns green when connected.
3. Play music and move the pen: tilt for bass, sway sideways for mids, twist
   for treble. Each gesture boosts one way and cuts the other; the pen at
   rest leaves the music flat.

Closing the app hands your speakers back automatically.

## 2. Start the app on Windows

First time only. VB-CABLE is the Windows loopback device (the BlackHole
equivalent). In an administrator PowerShell (right-click Start > Terminal
(Admin)), then reboot:

```powershell
curl.exe -L -o $env:TEMP\vbcable.zip https://download.vb-audio.com/Download_CABLE/VBCABLE_Driver_Pack45.zip
Expand-Archive $env:TEMP\vbcable.zip $env:TEMP\vbcable -Force
& $env:TEMP\vbcable\VBCABLE_Setup_x64.exe    # click "Install Driver"
shutdown /r /t 0
```

After the reboot, in a normal PowerShell:

```powershell
git clone https://github.com/Brillar0101/pen-mixer.git
cd pen-mixer\app
python -m venv venv
venv\Scripts\pip install -r requirements.txt -e .
```

Every time:

```powershell
cd pen-mixer\app
venv\Scripts\python -m penmixer.app
```

In Windows: Settings > System > Sound > Output > "CABLE Input (VB-Audio
Virtual Cable)". In the window:

1. Click "Hear music here". The app picks "CABLE Output" as input and your
   speakers as output and starts the audio; music is audible again through
   the app.
2. Set Source to "Bluetooth (pen board)", or click "Scan Bluetooth" and pick
   `PenMixer-Lexy`. The banner turns green when connected.
3. Play music and move the pen, as on macOS.

When you are done, set the Windows output back to your speakers; on Windows
the app cannot restore it for you.

## No board handy

Set Source to "Simulate (no board)". Synthetic pen motion sweeps all three
bands so the whole pipeline demos untethered.

## Troubleshooting

- Waves do not move: the system output is not routed to the loopback device.
  On macOS click "Route system audio here"; on Windows set the output to
  "CABLE Input". The status line says "input is silent" after two seconds
  when this is the case.
- Routed but silent: the music itself stopped, or the browser tab is bound
  to the old audio device. Reload the tab and press play.
- Banner stays red on Bluetooth: the board is not advertising. Is it powered
  and running `code.py`? Is anything else (another laptop, the soak test)
  already connected to it? Only one central can hold the link.
- "CABLE Output" missing on Windows: the VB-CABLE install needs the reboot;
  after it, click Rescan in the app. Do not use "Stereo Mix" instead; it
  feeds the app's own output back into it.
- Sound seems muffled: raise the Volume slider (default +9 dB restores unity
  against the input headroom pad), and on Bluetooth headphones make sure
  nothing is using their microphone, which drops them to phone quality.
- "No module named penmixer": run `pip install -e .` from `app/`; the dot
  matters.

## Legacy: the bridge and Pure Data stack

Before the Qt app, the laptop side was `prototype/bridge.py` feeding Pure Data
patches over UDP with a browser dashboard on port 8080. It still runs:

```sh
pip install bleak
python3 prototype/bridge.py            # USB serial, auto-detects the port
python3 prototype/bridge.py --ble      # BLE instead of the cable
```

Then open a patch from `prototype/patches/` in Pure Data (`pen-mixer-track.pd`
plays a file, `pen-mixer-live.pd` processes live input, `pen-mixer-manual.pd`
is sliders only), turn DSP on, and open `localhost:8080` for the dashboard.
Flags: `--port` to pin the serial device, `--alpha` for smoothing, `--web`
for the dashboard port, `--quiet` to silence per-frame logging. The Qt app
replaces all of this in one window and is the recommended path.

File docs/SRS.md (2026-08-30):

# System requirements specification

Requirements for the Mixer Pen, taken from the client brief and the academic
rubric. Each one is marked with where it stands: **v1** means it works today,
**v2** means it is planned for the second version. Nothing here is quietly
dropped; if v1 misses a requirement, the table says so.

## Functional requirements

| # | Requirement | Status |
|---|---|---|
| F1 | Some form of feedback | **v1.** Two kinds: the audio itself changes live, and the dashboard at localhost:8080 shows tilt and twist as you move. |
| F2 | Manipulate sound and get better at it | **v1.** Continuous control with 24 ms smoothing, so small hand improvements are audible. |
| F3 | Gesture rewards practice | **v1.** The mapping is deterministic and repeatable; a practiced gesture lands the same filter sweep every time. |
| F4 | Bluetooth link to the laptop, controlling the audio player | **v1.** BLE (Nordic UART) to bridge.py, which drives Pure Data over UDP. |

## Pen direction mapping

The brief asks for a three-band EQ mapped to pen motion. v1 ships a simpler
mapping (tilt sweeps one filter, twist moves gain) that proves the pipeline.
The full three-band mapping is v2 work in firmware and the Pure Data patch;
no hardware change is needed, the IMU already measures all three axes.

| # | Requirement | Status |
|---|---|---|
| M1 | Bass 60-250 Hz on vertical motion (y), like writing an "l" | **v2.** |
| M2 | Mids 250 Hz-2 kHz on horizontal motion (x), like crossing a "t"; left cuts, right boosts | **v2.** |
| M3 | Treble 2-20 kHz on orientation, upright (90&deg;) as base; leaning toward 0&deg; adds brightness | **v2.** Closest to today's tilt-sweeps-filter behavior. |

## Physical requirements

| # | Requirement | Status |
|---|---|---|
| P1 | At most 30 mm in both directions | **v2.** The v1 board is 11 x 42 mm; the USB-C connector and the antenna keep-out stretched it. v2 shrinks it by dropping USB-C for charge pads or folding the layout. |
| P2 | Clear casing | **v2.** No enclosure exists yet. Planned as a clear resin or polycarbonate shell over the board and battery. |
| P3 | Weight at most 1 oz (28 g) | **v1 by design.** Board plus battery is roughly 5 g. Stays met with any reasonable casing; final weight gets measured in v2 with the shell on. |
| P4 | Runs 3 hours at once | **v1 by design.** The 100 mAh cell against a ~6 mA average BLE draw estimates well past 3 h. Estimated, not yet measured; a soak test is on the v2 checklist. |
| P5 | Attaches to the top of a pen, semi-universal, ~3 mm of adjustment | **v2.** v1 mounts with a hose clamp for bench testing. v2 gets a sprung or rubber-lined clip sized for a mechanical pencil, a number 2 pencil, and a Bic. |
| P6 | On and off with one hand, rubber for grip | **v2.** Part of the same clip design as P5. |
| P7 | Position near the top, on top or beside it | **v1.** The mount already targets the top of the pen; the mapping does not care which side. |

## Open questions from the brief

| # | Question | Answer |
|---|---|---|
| Q1 | Can we include an NFC chip? | **v2, and cheaply.** The nRF52840 inside the ISP1807 has an NFC-A tag peripheral built in; the module exposes the NFC1/NFC2 pins. v2 adds only a small antenna coil and a tuning capacitor. |
| Q2 | Song requests over NFC, e.g. pass a YouTube link to the chip | **v2.** The tag can carry an NDEF record with a URL that a phone tap reads, and the laptop bridge can rewrite it over BLE. Fetching audio from YouTube itself stays on the laptop side and depends on the source being licensed. |

## What v2 is, in one list

Three-band EQ mapping (M1-M3), the 30 mm board (P1), the clear casing (P2),
the one-handed adjustable clip (P5, P6), the NFC antenna and song-request
flow (Q1, Q2), and measured numbers for weight and battery life (P3, P4).

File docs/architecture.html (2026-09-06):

Pen Mixer Architecture

System documentation

# How a pen ends up controlling a filter

Numbers on this page are measured on the working rig, not estimated. Where something is estimated or unverified it says so.

## Signal chain

Two transports, one discard path, and two loops. The loops are the parts that took longest to get right, so they are drawn rather than described.

on the pen on the laptop failure path dashed = intermittent

The bridge is drawn largest because it holds all three transforms and most of the tuning. The red edge is the discard path: any frame that does not split into three floats is dropped and counted, and the dashboard shows that counter. Both loops are real. BLE re-advertises after a disconnect, and Pd reopens the file at end of playback, which is the only reason the track repeats.

The 197 Hz gap: USB scheduling plus CircuitPython's print() overhead against a 250 Hz target. It has not caused problems, but it means the smoothing figures below settle slightly slower in practice than the table says.

## Production board

13 x 35 mm, four layers, 0.8 mm, all SMD. Two constraints drive the whole layout, and one of them dictates the board's shape.

The cell cannot feed the module directly: it runs to 4.2 V and the module's ceiling is 3.6 V, so it returns through the LDO. The keep-out is drawn full height because it is the constraint that decides the board's shape, not a footnote to it.

Unverified: the ISP1807 land pattern in stylus.pretty/ was reconstructed from the datasheet drawing. Pad numbering is read from the datasheet figure and is correct; the coordinates are derived. On a 0.65 mm pitch 78-pad LGA, check it against Insight SiP's official land pattern before paying for fabrication.

## Smoothing

Measured settling to 95% of a step at 250 Hz. Past roughly 20 ms end to end the instrument stops feeling connected to your hand.

alpha | settles in | feel
0.05 | 236 ms | unusable
0.15 | 76 ms | visibly behind your hand
0.4 | 24 ms | the default
0.5 | 20 ms | snappier, more jitter through
1.0 | 0 ms | raw, audible clicks on the filter

Smoothing eats 24 of the 32 ms budget and it is the only term you can change freely. A one-pole filter picks one setting for both fast and slow motion. A one-euro filter adapts instead, and that is the right fix once the mapping stops changing.

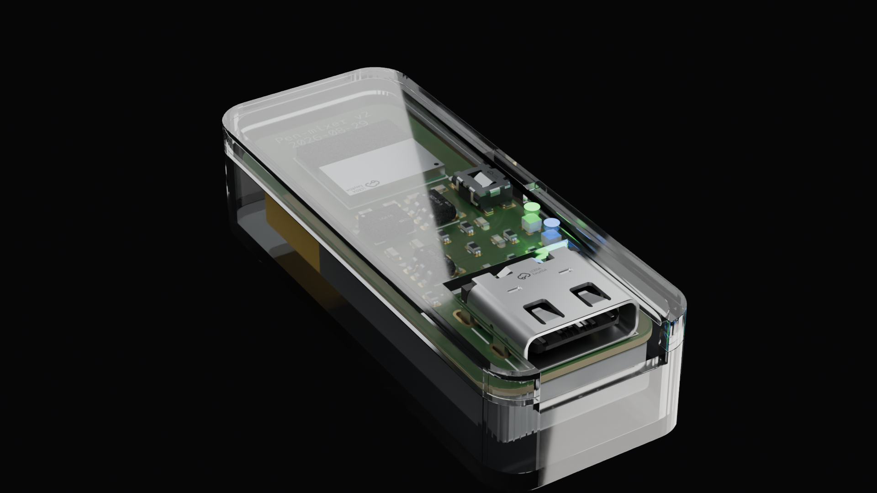
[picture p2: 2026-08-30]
production/blender/render-case.png

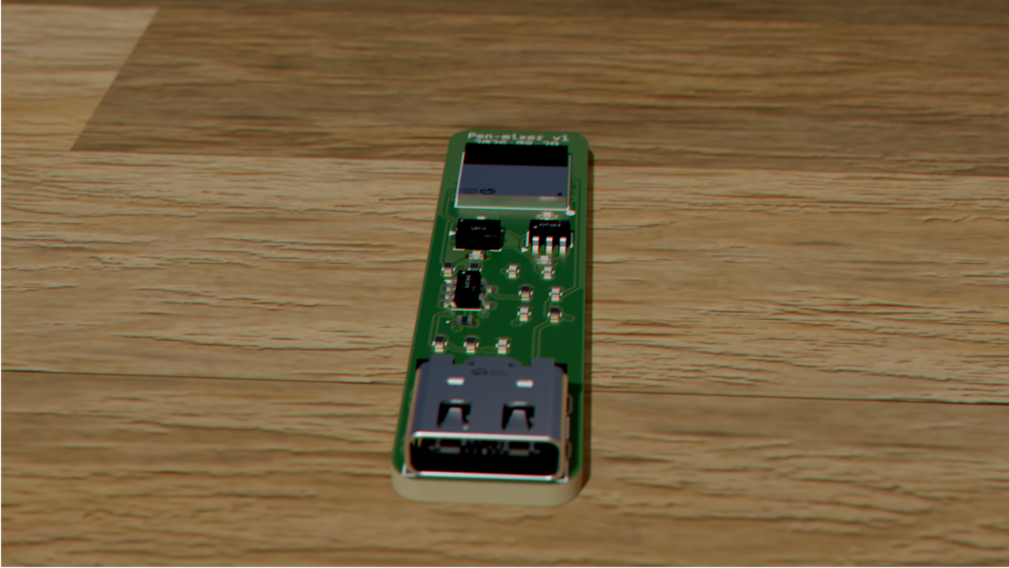
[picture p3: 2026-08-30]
production/blender/render-cappuccino.png

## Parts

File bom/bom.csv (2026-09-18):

Reference | Value | Footprint | Qty | MPN | Manufacturer | LCSC | Notes
C1,C2 | 4u7 | Capacitor_SMD:C_0402_1005Metric | 2 | CL05A475MP5NRNC | Samsung Electro-Mechanics | C23733
C3,C4 | 1u | Capacitor_SMD:C_0402_1005Metric | 2 | CL05A105KA5NQNC | Samsung Electro-Mechanics | C52923
C5,C7,C8,C10,C11 | 100n | Capacitor_SMD:C_0402_1005Metric | 5 | CL05B104KO5NNNC | Samsung Electro-Mechanics | C1525
C6 | 10u | Capacitor_SMD:C_0402_1005Metric | 1 | CGA0402X5R106M6R3GT | TDK | C23692971
D1 | GRN | LED_SMD:LED_0402_1005Metric | 1 | NCD0402G1 | Foshan NationStar | C130723
J1 | USB-C 16P | pen-mixer:GT-USB-7010ASV | 1 | GT-USB-7010ASV | G-Switch | C2988369 | v3.1: side-entry receptacle recessed in the bottom notch, 3.2 mm tall, lies flat
J2 | BAT | pen-mixer:SolderPad_1.2x2.0mm | 1 |  |  |  | bare solder pads - battery wires solder here, no part to order
LED1,LED2 | XL-1010RGBC | pen-mixer:LED-SMD_4P-L1.0-W1.0-TL_XL-1010RGBC-WS2812B | 2 | XL-1010RGBC-2812B | XINGLIGHT | C5349953 | battery level indicator (left arm),bluetooth status indicator (right arm)
R1,R2 | 5k1 | Resistor_SMD:R_0402_1005Metric | 2 | 0402WGF5101TCE | UNI-ROYAL | C25905
R3 | 20k | Resistor_SMD:R_0402_1005Metric | 1 | 0402WGF2002TCE | UNI-ROYAL | C25765
R4 | 1k | Resistor_SMD:R_0402_1005Metric | 1 | 0402WGF1001TCE | UNI-ROYAL | C11702
R6,R7 | 4k7 | Resistor_SMD:R_0402_1005Metric | 2 | 0402WGF4701TCE | UNI-ROYAL | C25900
R8,R9 | 1M | Resistor_SMD:R_0402_1005Metric | 2 | 0402WGF1004TCE | UNI-ROYAL | C26083
SW1 | EVQP7C01P | pen-mixer:SW-SMD_EVQP7C01P | 1 | EVQP7C01P | PANASONIC | C388883 | power and pairing button, side actuated
TP1 | SWDIO | pen-mixer:TestPad_1.0mm | 1
TP2 | SWDCLK | pen-mixer:TestPad_1.0mm | 1
TP4 | GND | pen-mixer:TestPad_1.0mm | 1
TP5 | +3V3 | pen-mixer:TestPad_1.0mm | 1
U1 | ISP1807-LR | pen-mixer:BULETM-SMD_ISP1807 | 1 | ISP1807-LR-RS | Insight SiP | C5264268 | 0 stock at JLC/LCSC - source from Mouser or DigiKey
U2 | LSM6DS3TR-C | Package_LGA:LGA-14_3x2.5mm_P0.5mm_LayoutBorder3x4y | 1 | LSM6DS3TR-C | STMicroelectronics | C967633
U3 | MCP73831T-2ACI/OT | Package_TO_SOT_SMD:SOT-23-5 | 1 | MCP73831T-2ACI/OT | Microchip | C424093
U4 | TPS7A0533PDBV | Package_TO_SOT_SMD:SOT-23-5 | 1 | TPS7A0533PDBVR | Texas Instruments | C493453

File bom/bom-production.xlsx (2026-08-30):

Pen Mixer production board BOM
v2.1, 13 x 35 mm 4-layer 0.6 mm. Exported from KiCad, assembled at JLCPCB with LCSC parts. Quantities per board.
Reference | Qty | Value | Footprint | MPN | Manufacturer | LCSC | Unit price (USD) | Line total (USD) | Source | Notes
C1,C2 | 2 | 4u7 | C_0402_1005Metric | CL05A475MP5NRNC | Samsung Electro-Mechanics | C23733 | 0.0232 | 0.05 | JLCPCB
C3,C4 | 2 | 1u | C_0402_1005Metric | CL05A105KA5NQNC | Samsung Electro-Mechanics | C52923 | 0.0120 | 0.02 | JLCPCB
C5,C7,C8,C10,C11 | 5 | 100n | C_0402_1005Metric | CL05B104KO5NNNC | Samsung Electro-Mechanics | C1525 | 0.0055 | 0.03 | JLCPCB
C6 | 1 | 10u | C_0402_1005Metric | CGA0402X5R106M6R3GT | TDK | C23692971 | 0.0244 | 0.02 | JLCPCB
D1 | 1 | GRN | LED_0402_1005Metric | NCD0402G1 | Foshan NationStar | C130723 | 0.0447 | 0.04 | JLCPCB
J1 | 1 | USB-C 16P | USB_C_Receptacle_G-Switch_GT-USB-7010ASV | GT-USB-7010ASV | G-Switch | C2988369 | 0.0875 | 0.09 | JLCPCB
J2 | 1 | BAT | SolderPad_1.2x2.0mm |  |  |  |  |  |  | bare solder pads - battery wires solder here, no part to order
LED1,LED2 | 2 | XL-1010RGBC | LED-SMD_4P-L1.0-W1.0-TL_XL-1010RGBC-WS2812B | XL-1010RGBC-2812B | XINGLIGHT | C5349953 | 0.0748 | 0.15 | JLCPCB | battery level indicator,bluetooth status indicator
R1,R2 | 2 | 5k1 | R_0402_1005Metric | 0402WGF5101TCE | UNI-ROYAL | C25905 | 0.0026 | 0.01 | JLCPCB
R3 | 1 | 20k | R_0402_1005Metric | 0402WGF2002TCE | UNI-ROYAL | C25765 | 0.0024 | 0.0024 | JLCPCB
R4 | 1 | 1k | R_0402_1005Metric | 0402WGF1001TCE | UNI-ROYAL | C11702 | 0.0039 | 0.0039 | JLCPCB
R6,R7 | 2 | 4k7 | R_0402_1005Metric | 0402WGF4701TCE | UNI-ROYAL | C25900 | 0.0029 | 0.01 | JLCPCB
R8,R9 | 2 | 1M | R_0402_1005Metric | 0402WGF1004TCE | UNI-ROYAL | C26083 | 0.0026 | 0.01 | JLCPCB
SW1 | 1 | EVQP7C01P | SW-SMD_EVQP7C01P | EVQP7C01P | PANASONIC | C388883 | 0.1849 | 0.18 | JLCPCB | power and pairing button, side actuated
TP1 | 1 | SWDIO | TestPad_1.0mm |  |  |  |  |  |  | bare pads, nothing to order
TP2 | 1 | SWDCLK | TestPad_1.0mm |  |  |  |  |  |  | bare pads, nothing to order
TP4 | 1 | GND | TestPad_1.0mm |  |  |  |  |  |  | bare pads, nothing to order
TP5 | 1 | +3V3 | TestPad_1.0mm |  |  |  |  |  |  | bare pads, nothing to order
U1 | 1 | ISP1807-LR | BULETM-SMD_ISP1807 | ISP1807-LR-RS | Insight SiP | C5264268 | 12.1151 | 12.12 | Mouser/DigiKey (consign) | 0 stock at JLC/LCSC - source from Mouser or DigiKey
U2 | 1 | LSM6DS3TR-C | LGA-14_3x2.5mm_P0.5mm_LayoutBorder3x4y | LSM6DS3TR-C | STMicroelectronics | C967633 | 1.5538 | 1.55 | JLCPCB
U3 | 1 | MCP73831T-2ACI/OT | SOT-23-5 | MCP73831T-2ACI/OT | Microchip | C424093 | 0.8596 | 0.86 | JLCPCB
U4 | 1 | TPS7A0533PDBV | SOT-23-5 | TPS7A0533PDBVR | Texas Instruments | C493453 | 0.2777 | 0.28 | JLCPCB
Parts total per board |  |  |  |  |  |  |  | 15.42
Ordering notes
Order PCB + assembly at jlcpcb.com with the gerbers, BOM and CPL in production/output/ (regenerate before ordering).
U1 ISP1807-LR-RS: 0 stock at JLCPCB/LCSC. Buy from Mouser or DigiKey and consign, or hand-place.
v2.1 additions: LED1/LED2 XL-1010RGBC addressable RGB, SW1 EVQP7C01P side switch, C11 100n.
J2 battery pads and the four test pads are bare copper, nothing to order.
Case: two clear shells via JLCPCB 3D printing (8001 resin); battery 401230 LiPo from Amazon.

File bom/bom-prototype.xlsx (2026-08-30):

Pen Mixer prototype BOM
Off-the-shelf build on the Seeed XIAO nRF52840 Sense. Everything ordered from Amazon; prices approximate.
Item | Part | Qty | Est. cost (USD) | Source | Amazon search term | Notes
Core build
Motion board | Seeed XIAO nRF52840 Sense | 1 | 20.00 | Amazon | Seeed Studio XIAO nRF52840 Sense | A few dollars over Seeed direct, but arrives in days
Pen | Any ballpoint, thicker barrel | 1 | 2.00 | Amazon | ballpoint pen thick barrel
USB-C cable | Data-capable (not charge-only) | 1 | 8.00 | Amazon | USB-C data cable | Charge-only cables will not enumerate
Wireless option
LiPo cell | 3.7 V 300 mAh, JST-PH 2.0, protected | 1 | 10.00 | Amazon | 3.7V 300mAh LiPo JST-PH 2.0 protection | Check polarity against the XIAO silkscreen before plugging
Slide switch | SPDT | 1 | 6.00 | Amazon | SPDT slide switch small | Sold in multipacks
Total, everything |  |  | 46.00
Keep metal away from the USB-C end of the XIAO: the BLE antenna lives there.
Nothing conductive may touch the exposed pads on the back of the board.
Leave the BAT pads uncovered if the cell might be added later.
Laptop software (Pure Data, bridge, dashboard) is free and not part of this BOM.

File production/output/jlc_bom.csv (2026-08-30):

Comment | Designator | Footprint | LCSC Part # | MPN | Manufacturer | Quantity | Notes
4u7 | C1,C2 | Capacitor_SMD:C_0402_1005Metric | C23733 | CL05A475MP5NRNC | Samsung Electro-Mechanics | 2
1u | C3,C4 | Capacitor_SMD:C_0402_1005Metric | C52923 | CL05A105KA5NQNC | Samsung Electro-Mechanics | 2
100n | C5,C7,C8,C10,C11 | Capacitor_SMD:C_0402_1005Metric | C1525 | CL05B104KO5NNNC | Samsung Electro-Mechanics | 5
10u | C6 | Capacitor_SMD:C_0402_1005Metric | C23692971 | CGA0402X5R106M6R3GT | TDK | 1
GRN | D1 | LED_SMD:LED_0402_1005Metric | C130723 | NCD0402G1 | Foshan NationStar | 1
USB-C 16P | J1 | Connector_USB:USB_C_Receptacle_G-Switch_GT-USB-7010ASV | C2988369 | GT-USB-7010ASV | G-Switch | 1
BAT | J2 | pen-mixer:SolderPad_1.2x2.0mm |  |  |  | 1
XL-1010RGBC | LED1,LED2 | pen-mixer:LED-SMD_4P-L1.0-W1.0-TL_XL-1010RGBC-WS2812B | C5349953 | XL-1010RGBC-2812B | XINGLIGHT | 2
5k1 | R1,R2 | Resistor_SMD:R_0402_1005Metric | C25905 | 0402WGF5101TCE | UNI-ROYAL | 2
20k | R3 | Resistor_SMD:R_0402_1005Metric | C25765 | 0402WGF2002TCE | UNI-ROYAL | 1
1k | R4 | Resistor_SMD:R_0402_1005Metric | C11702 | 0402WGF1001TCE | UNI-ROYAL | 1
4k7 | R6,R7 | Resistor_SMD:R_0402_1005Metric | C25900 | 0402WGF4701TCE | UNI-ROYAL | 2
1M | R8,R9 | Resistor_SMD:R_0402_1005Metric | C26083 | 0402WGF1004TCE | UNI-ROYAL | 2
EVQP7C01P | SW1 | pen-mixer:SW-SMD_EVQP7C01P | C388883 | EVQP7C01P | PANASONIC | 1
SWDIO | TP1 | pen-mixer:TestPad_1.0mm |  |  |  | 1
SWDCLK | TP2 | pen-mixer:TestPad_1.0mm |  |  |  | 1
GND | TP4 | pen-mixer:TestPad_1.0mm |  |  |  | 1
+3V3 | TP5 | pen-mixer:TestPad_1.0mm |  |  |  | 1
ISP1807-LR | U1 | pen-mixer:BULETM-SMD_ISP1807 | C5264268 | ISP1807-LR-RS | Insight SiP | 1
LSM6DS3TR-C | U2 | Package_LGA:LGA-14_3x2.5mm_P0.5mm_LayoutBorder3x4y | C967633 | LSM6DS3TR-C | STMicroelectronics | 1
MCP73831T-2ACI/OT | U3 | Package_TO_SOT_SMD:SOT-23-5 | C424093 | MCP73831T-2ACI/OT | Microchip | 1
TPS7A0533PDBV | U4 | Package_TO_SOT_SMD:SOT-23-5 | C493453 | TPS7A0533PDBVR | Texas Instruments | 1

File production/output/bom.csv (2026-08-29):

Reference | Value | Footprint | QUANTITY
C1,C2 | 4u7 | Capacitor_SMD:C_0402_1005Metric | 2
C3,C4 | 1u | Capacitor_SMD:C_0402_1005Metric | 2
C5,C7-C10 | 100n | Capacitor_SMD:C_0402_1005Metric | 5
C6 | 10u | Capacitor_SMD:C_0402_1005Metric | 1
D1 | GRN | LED_SMD:LED_0402_1005Metric | 1
J1 | USB-C 16P | Connector_USB:USB_C_Receptacle_G-Switch_GT-USB-7010ASV | 1
J2 | BAT | pen-mixer:SolderPad_1.2x2.0mm | 1
J3 | FSR | pen-mixer:SolderPad_1.2x2.0mm | 1
R1,R2 | 5k1 | Resistor_SMD:R_0402_1005Metric | 2
R3 | 20k | Resistor_SMD:R_0402_1005Metric | 1
R4 | 1k | Resistor_SMD:R_0402_1005Metric | 1
R5 | 10k | Resistor_SMD:R_0402_1005Metric | 1
R6,R7 | 4k7 | Resistor_SMD:R_0402_1005Metric | 2
R8,R9 | 1M | Resistor_SMD:R_0402_1005Metric | 2
TP1 | SWDIO | pen-mixer:TestPad_1.0mm | 1
TP2 | SWDCLK | pen-mixer:TestPad_1.0mm | 1
TP4 | GND | pen-mixer:TestPad_1.0mm | 1
TP5 | +3V3 | pen-mixer:TestPad_1.0mm | 1
U1 | ISP1807-LR | pen-mixer:ISP1807-LR | 1
U2 | LSM6DS3TR-C | Package_LGA:LGA-14_3x2.5mm_P0.5mm_LayoutBorder3x4y | 1
U3 | MCP73831T-2ACI/OT | Package_TO_SOT_SMD:SOT-23-5 | 1
U4 | TPS7A0533PDBV | Package_TO_SOT_SMD:SOT-23-5 | 1

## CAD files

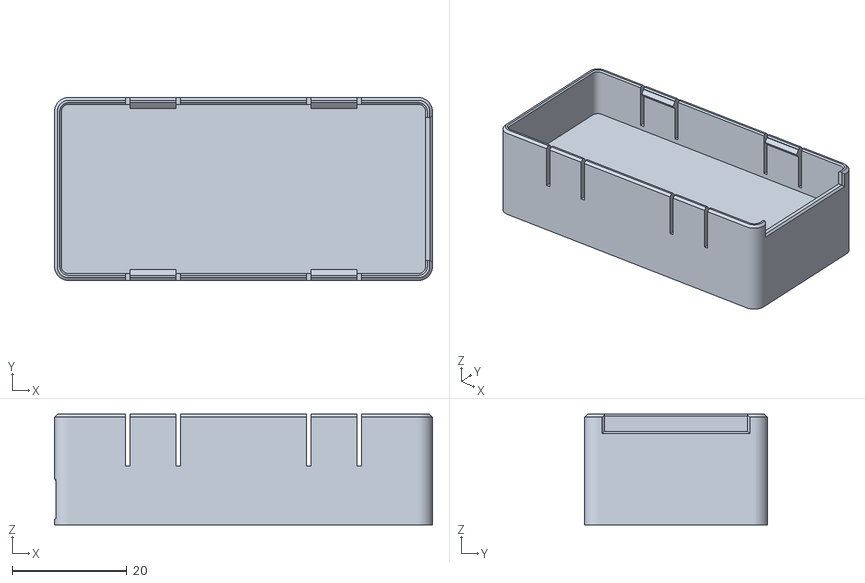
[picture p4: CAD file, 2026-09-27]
production/case-stars/top.stl
65.9 x 31.9 x 19.3

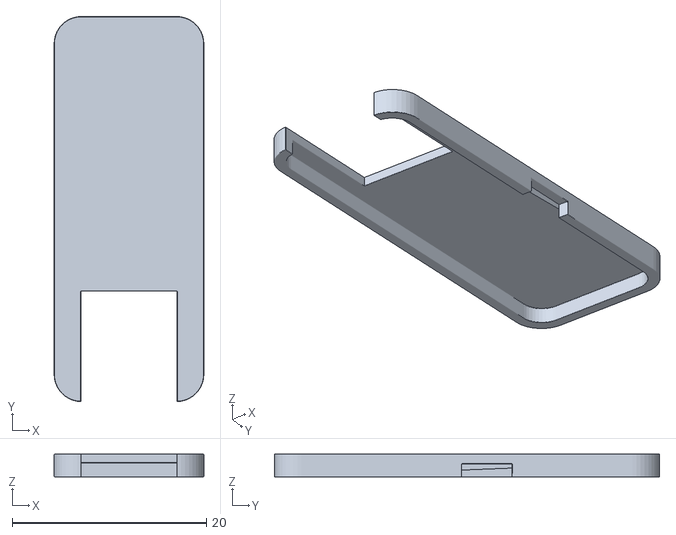
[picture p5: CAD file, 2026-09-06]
production/output/case/case_top.stl
15.4 x 39.6 x 2.35

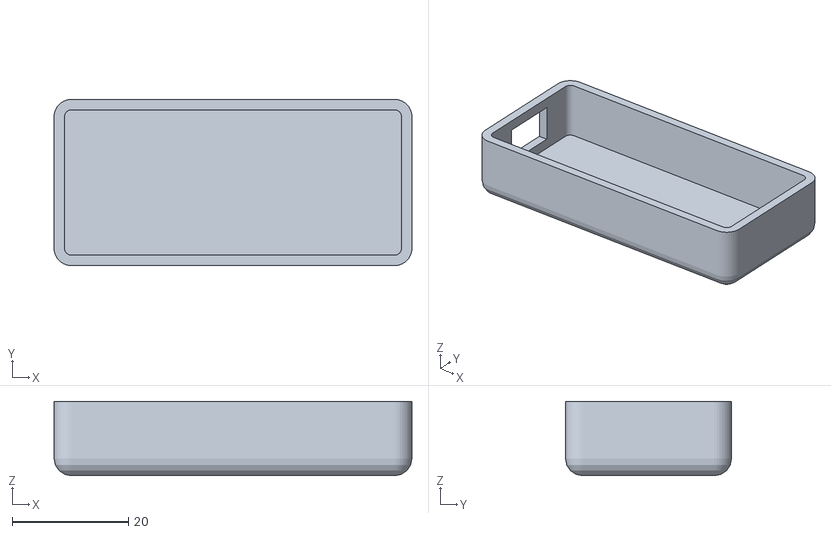
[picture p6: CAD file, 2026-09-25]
production/output/case_proto/case_proto_bottom.stl
61.6 x 28.6 x 12.8

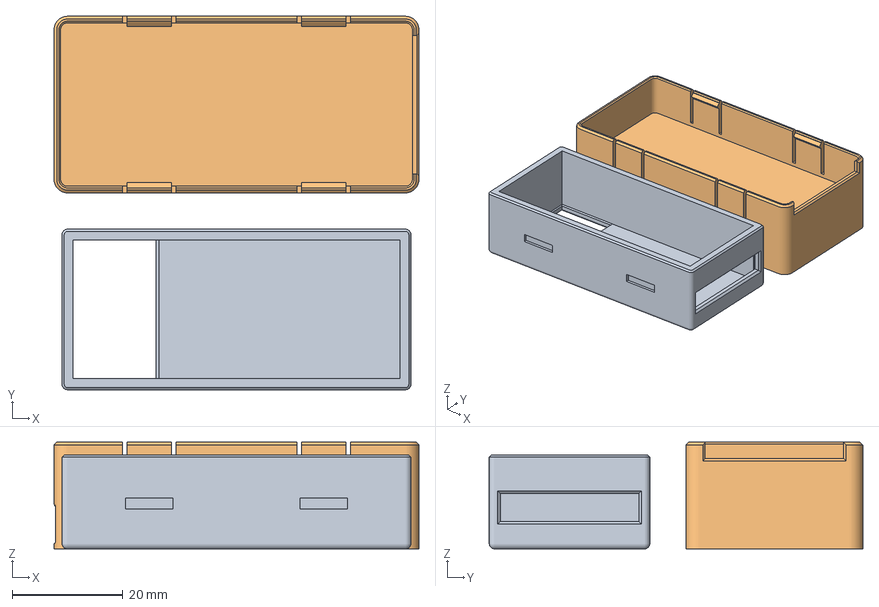
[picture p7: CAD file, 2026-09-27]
production/case-stars/stars.3mf
65.9 x 67.4 x 19.3 mm
tray (bottom)
lid with slab rails

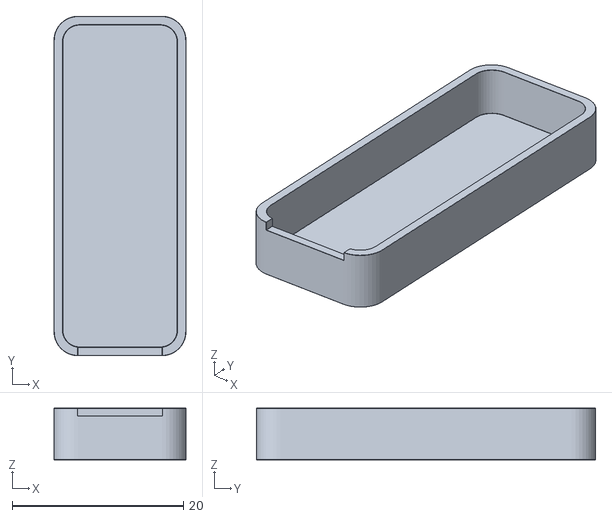
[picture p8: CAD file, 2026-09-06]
production/output/case/case_bottom.stl
15.4 x 39.6 x 6.05

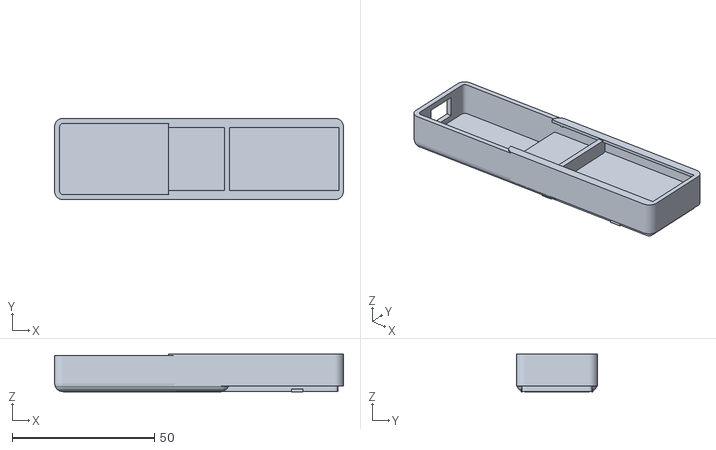
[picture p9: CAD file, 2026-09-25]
production/output/case_proto/case_proto_both.stl
101.6 x 28.6 x 13.2

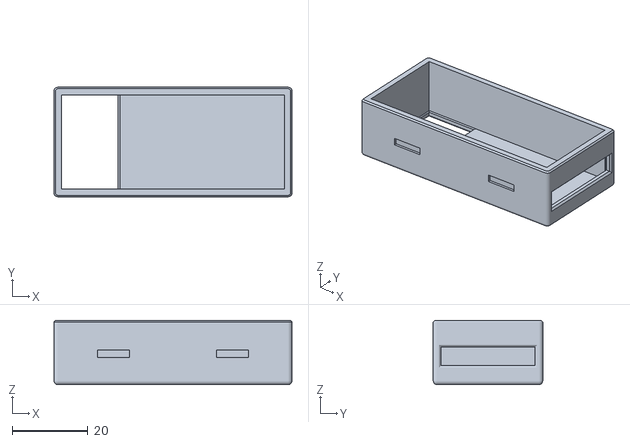
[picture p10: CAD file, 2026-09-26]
production/case-stars/bottom.stl
63.0 x 29.0 x 17.0

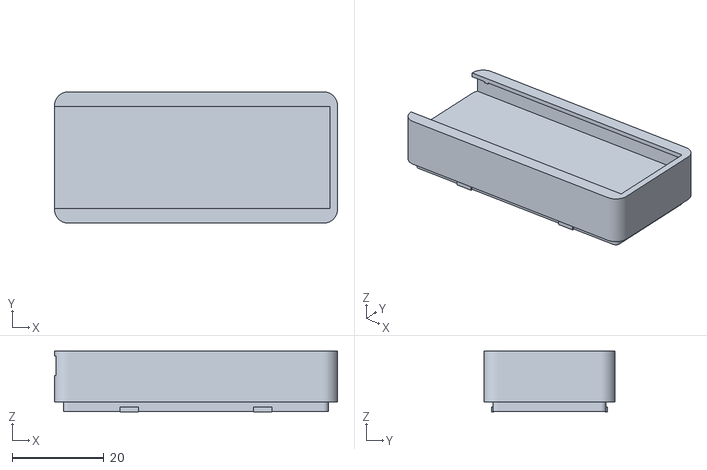
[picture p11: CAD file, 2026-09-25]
production/output/case_proto/case_proto_top.stl
61.6 x 28.6 x 13.2

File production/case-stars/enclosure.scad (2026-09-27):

// Dimensions in millimetres. Export bottom and top separately for printing.
part = "layout"; // [layout,bottom,top,assembled,exploded,interference]
inner_length = 59;
inner_width = 25;
inner_height = 15;
wall = 2;
floor_thickness = 2;
roof_thickness = 2;
clearance = 0.25; // Per side, outside the usable cavity.
skirt_thickness = 1.2;
skirt_depth = 10;
tab_width = 8;
slot_width = 0.8;
hook_projection = 0.70;
pocket_depth = 0.70;
floor_opening_length = 15;
end_opening_height = 5;
end_opening_above_floor = 3;
// Edge softening. Bed-side fillets print as short shallow overhangs on the first layers.
edge_fillet = 1.0;     // Roof top edges and tray bottom edges.
rim_chamfer = 0.4;     // Tray rim outer edge; doubles as a lead-in for the lid.
skirt_chamfer = 0.5;   // Skirt tip outer edge.
skirt_lead_in = 0.3;   // Skirt tip inner edge.
opening_chamfer = 0.5; // Both faces of the port and floor cut-outs.
notch_chamfer = 0.4;   // Outer face of the lid skirt notch.
$fn = 48;
eps = 0.01;
L = inner_length + 2*wall;
W = inner_width + 2*wall;
seat = floor_thickness + inner_height;
H = seat + roof_thickness;
OL = L + 2*(clearance + skirt_thickness);
OW = W + 2*(clearance + skirt_thickness);
tip_z = seat - skirt_depth;
hook_z = tip_z + 1.2;
tab_positions = [-L/4, L/4];
lid_corner = 2.45;
port_z = floor_thickness + end_opening_above_floor;
port_zc = port_z + end_opening_height/2;
floor_opening_xc = -inner_length/2 + floor_opening_length/2;

module rounded_prism(l,w,h,r) {
    linear_extrude(height=h)
        offset(r=r) square([l-2*r,w-2*r],center=true);
}

// Tori (spheres when rv==rf) at the four corners; hull with a prism to round its horizontal edges.
module fillet_ring(l,w,z,rv,rf) {
    for (sx=[-1,1], sy=[-1,1])
        translate([sx*(l/2-rv), sy*(w/2-rv), z])
            if (rv-rf > eps) rotate_extrude() translate([rv-rf,0]) circle(rf);
            else sphere(rf);
}

// 45 degree flare of an l x w opening at a face. Local +z points out of the material.
module flare(l,w,c) {
    hull() {
        translate([0,0,-c]) linear_extrude(eps) square([l,w],center=true);
        linear_extrude(2*eps) square([l+2*c,w+2*c],center=true);
    }
}

module tray_body() {
    hull() {
        fillet_ring(L,W,edge_fillet,1,edge_fillet);
        translate([0,0,edge_fillet])
            rounded_prism(L,W,seat-edge_fillet-rim_chamfer,1);
        translate([0,0,seat-eps])
            rounded_prism(L-2*rim_chamfer,W-2*rim_chamfer,eps,1-rim_chamfer);
    }
}

// Left = negative X, right = positive X along the 59 mm length.
module right_opening() {
    translate([inner_length/2-eps,-inner_width/2,port_z])
        cube([wall+clearance+skirt_thickness+2*eps,
              inner_width,end_opening_height]);
}

module port_flares() {
    translate([L/2,0,port_zc]) rotate([0,90,0])
        flare(end_opening_height,inner_width,opening_chamfer);
    translate([inner_length/2,0,port_zc]) rotate([0,-90,0])
        flare(end_opening_height,inner_width,opening_chamfer);
}

module floor_opening() {
    translate([-inner_length/2,-inner_width/2,-eps])
        cube([floor_opening_length,inner_width,floor_thickness+2*eps]);
    translate([floor_opening_xc,0,0]) rotate([180,0,0])
        flare(floor_opening_length,inner_width,opening_chamfer);
    translate([floor_opening_xc,0,floor_thickness])
        flare(floor_opening_length,inner_width,opening_chamfer);
}

module bottom() {
    difference() {
        tray_body();
        // Square internal corners preserve the complete rectangular cavity.
        translate([-inner_length/2,-inner_width/2,floor_thickness])
            cube([inner_length,inner_width,inner_height+eps]);
        for (x=tab_positions, side=[-1,1])
            translate([x,side*(W/2-pocket_depth/2+eps/2),hook_z])
                cube([tab_width+0.6,pocket_depth+eps,2.0],center=true);
        floor_opening();
        right_opening();
        port_flares();
    }
}

module hook(x, side) {
    // Both slopes are printable ramps; the upper slope permits reopening.
    translate([x,0,0]) scale([1,side,1]) hull() {
        translate([-tab_width/2,W/2+clearance,hook_z-0.8])
            cube([tab_width,0.10,0.02]);
        translate([-tab_width/2,W/2+clearance-hook_projection,hook_z])
            cube([tab_width,hook_projection+0.10,0.02]);
        translate([-tab_width/2,W/2+clearance,hook_z+0.8])
            cube([tab_width,0.10,0.02]);
    }
}

module lid_roof() {
    hull() {
        translate([0,0,seat])
            rounded_prism(OL,OW,roof_thickness-edge_fillet,lid_corner);
        fillet_ring(OL,OW,H-edge_fillet,lid_corner,edge_fillet);
    }
}

module skirt_outer() {
    hull() {
        translate([0,0,tip_z])
            rounded_prism(OL-2*skirt_chamfer,OW-2*skirt_chamfer,eps,lid_corner-skirt_chamfer);
        translate([0,0,tip_z+skirt_chamfer])
            rounded_prism(OL,OW,skirt_depth-skirt_chamfer+eps,lid_corner);
    }
}

module skirt_inner_cut() {
    il = L + 2*clearance;
    iw = W + 2*clearance;
    ir = 1 + clearance;
    translate([0,0,tip_z-eps]) rounded_prism(il,iw,skirt_depth+3*eps,ir);
    hull() {
        translate([0,0,tip_z-eps])
            rounded_prism(il+2*skirt_lead_in,iw+2*skirt_lead_in,eps,ir+skirt_lead_in);
        translate([0,0,tip_z+skirt_lead_in]) rounded_prism(il,iw,eps,ir);
    }
}

module top_assembled() {
    union() {
        lid_roof();
        difference() {
            skirt_outer();
            skirt_inner_cut();
            // Open-ended slots free four cantilevers, leaving a 1 mm root band.
            for (x=tab_positions, side=[-1,1], edge=[-1,1])
                translate([x+edge*(tab_width+slot_width)/2,
                           side*(W/2+clearance+skirt_thickness/2),
                           tip_z+(skirt_depth-1)/2-eps])
                    cube([slot_width,skirt_thickness+2,skirt_depth-1+2*eps],center=true);
            // Clear the overlapping skirt so it cannot cover the end port.
            right_opening();
            translate([OL/2,0,port_zc]) rotate([0,90,0])
                flare(end_opening_height,inner_width,notch_chamfer);
        }
        for (x=tab_positions,side=[-1,1]) hook(x,side);
    }
}


// Star cut-outs through the lid roof, kept inside the cavity footprint.
star_points = 5;
star_inner_ratio = 0.42;
stars = []; // [x, y, outer radius] -- stars removed; add entries to bring them back
module star2d(r) {
    polygon([for (i=[0:2*star_points-1])
        let(a = 90 + i*180/star_points, rr = (i%2==0) ? r : r*star_inner_ratio)
        [rr*cos(a), rr*sin(a)]]);
}
module star_cuts() {
    for (s = stars) translate([s[0], s[1], seat-1]) linear_extrude(roof_thickness+2) star2d(s[2]);
}

// Slide-in rails on the roof for a wooden slab. Enters at -X, stops at +X.
slab_len = 58; slab_wid = 27; slab_thk = 5;
slab_clear_w = 1.15;   // per side: channel is slab + 2.3 mm wide
slab_clear_h = 1.3;    // channel is slab + 1.3 mm tall
rail_lip = 2.5;        // lip reach from the channel wall; overlaps the slab by 1.35 mm
lip_thk = 1.0;
stop_wall = 1.6;
detent = 0.3;
rail_round = 0.45;     // edge radius on the rails and stop wall
// Round every convex and concave corner of a 2D profile by r.
module round2d(r) { offset(r=r) offset(delta=-r) offset(r=-r) offset(delta=r) children(); }
module slab_rails() {
    hx = slab_wid/2 + slab_clear_w;
    z0 = H - edge_fillet;   // fuses through the roof edge fillet
    zc = H + slab_thk + slab_clear_h;
    zt = zc + lip_thk;
    intersection() {
        translate([0,0,z0]) rounded_prism(OL,OW,zt-z0,lid_corner);
        union() {
            for (s=[-1,1]) scale([1,s,1]) {
                // rail wall and lip as one rounded profile swept along the length
                translate([-OL/2,0,0]) rotate([90,0,90]) linear_extrude(OL)
                    round2d(rail_round) union() {
                        translate([hx, z0 - 2*rail_round]) square([OW/2 - hx + 2*rail_round, zt - z0 + 2*rail_round]);
                        translate([hx - rail_lip, zc]) square([rail_lip + eps, lip_thk]);
                    }
                // detent under each lip at the entry end
                translate([-OL/2+1.5, hx-rail_lip, zc-detent]) cube([1, rail_lip, detent+eps]);
            }
            // stop wall with rounded top edges
            translate([0,OW/2+1,0]) rotate([90,0,0]) linear_extrude(OW+2)
                round2d(rail_round) translate([OL/2 - stop_wall, z0 - 2*rail_round]) square([stop_wall + 2*rail_round, zt - z0 + 2*rail_round]);
        }
    }
}
module top_with_stars() { difference() { union() { top_assembled(); slab_rails(); } star_cuts(); } }
rails_top = H + slab_thk + slab_clear_h + lip_thk;
// Separate glue-on frame. Printed lip side down: no bridges or overhangs.
module rails_print() { translate([0,0,rails_top]) rotate([180,0,0]) slab_rails(); }

module top_print() {
    translate([0,0,rails_top]) rotate([180,0,0]) top_with_stars();
}
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

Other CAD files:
production/blender/case_proto.blend
production/blender/pen-mixer.blend
production/case-stars/case_both.blend

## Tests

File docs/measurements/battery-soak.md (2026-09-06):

# Battery soak test

Status: NOT YET MEASURED. The first attempt (2026-09-06, XIAO nRF52840 Sense
on its cell, BLE streaming at ~65 fps) was cut short after 13 minutes when the
board was plugged back into USB, which ends the test and starts charging. That
run says nothing about battery life. Rerun with the board off USB for the
whole test:

    app/venv/bin/python prototype/tools/battery_soak.py

The script writes the runtime and the PRD P4 verdict (3 hours) here when the
cell runs down.

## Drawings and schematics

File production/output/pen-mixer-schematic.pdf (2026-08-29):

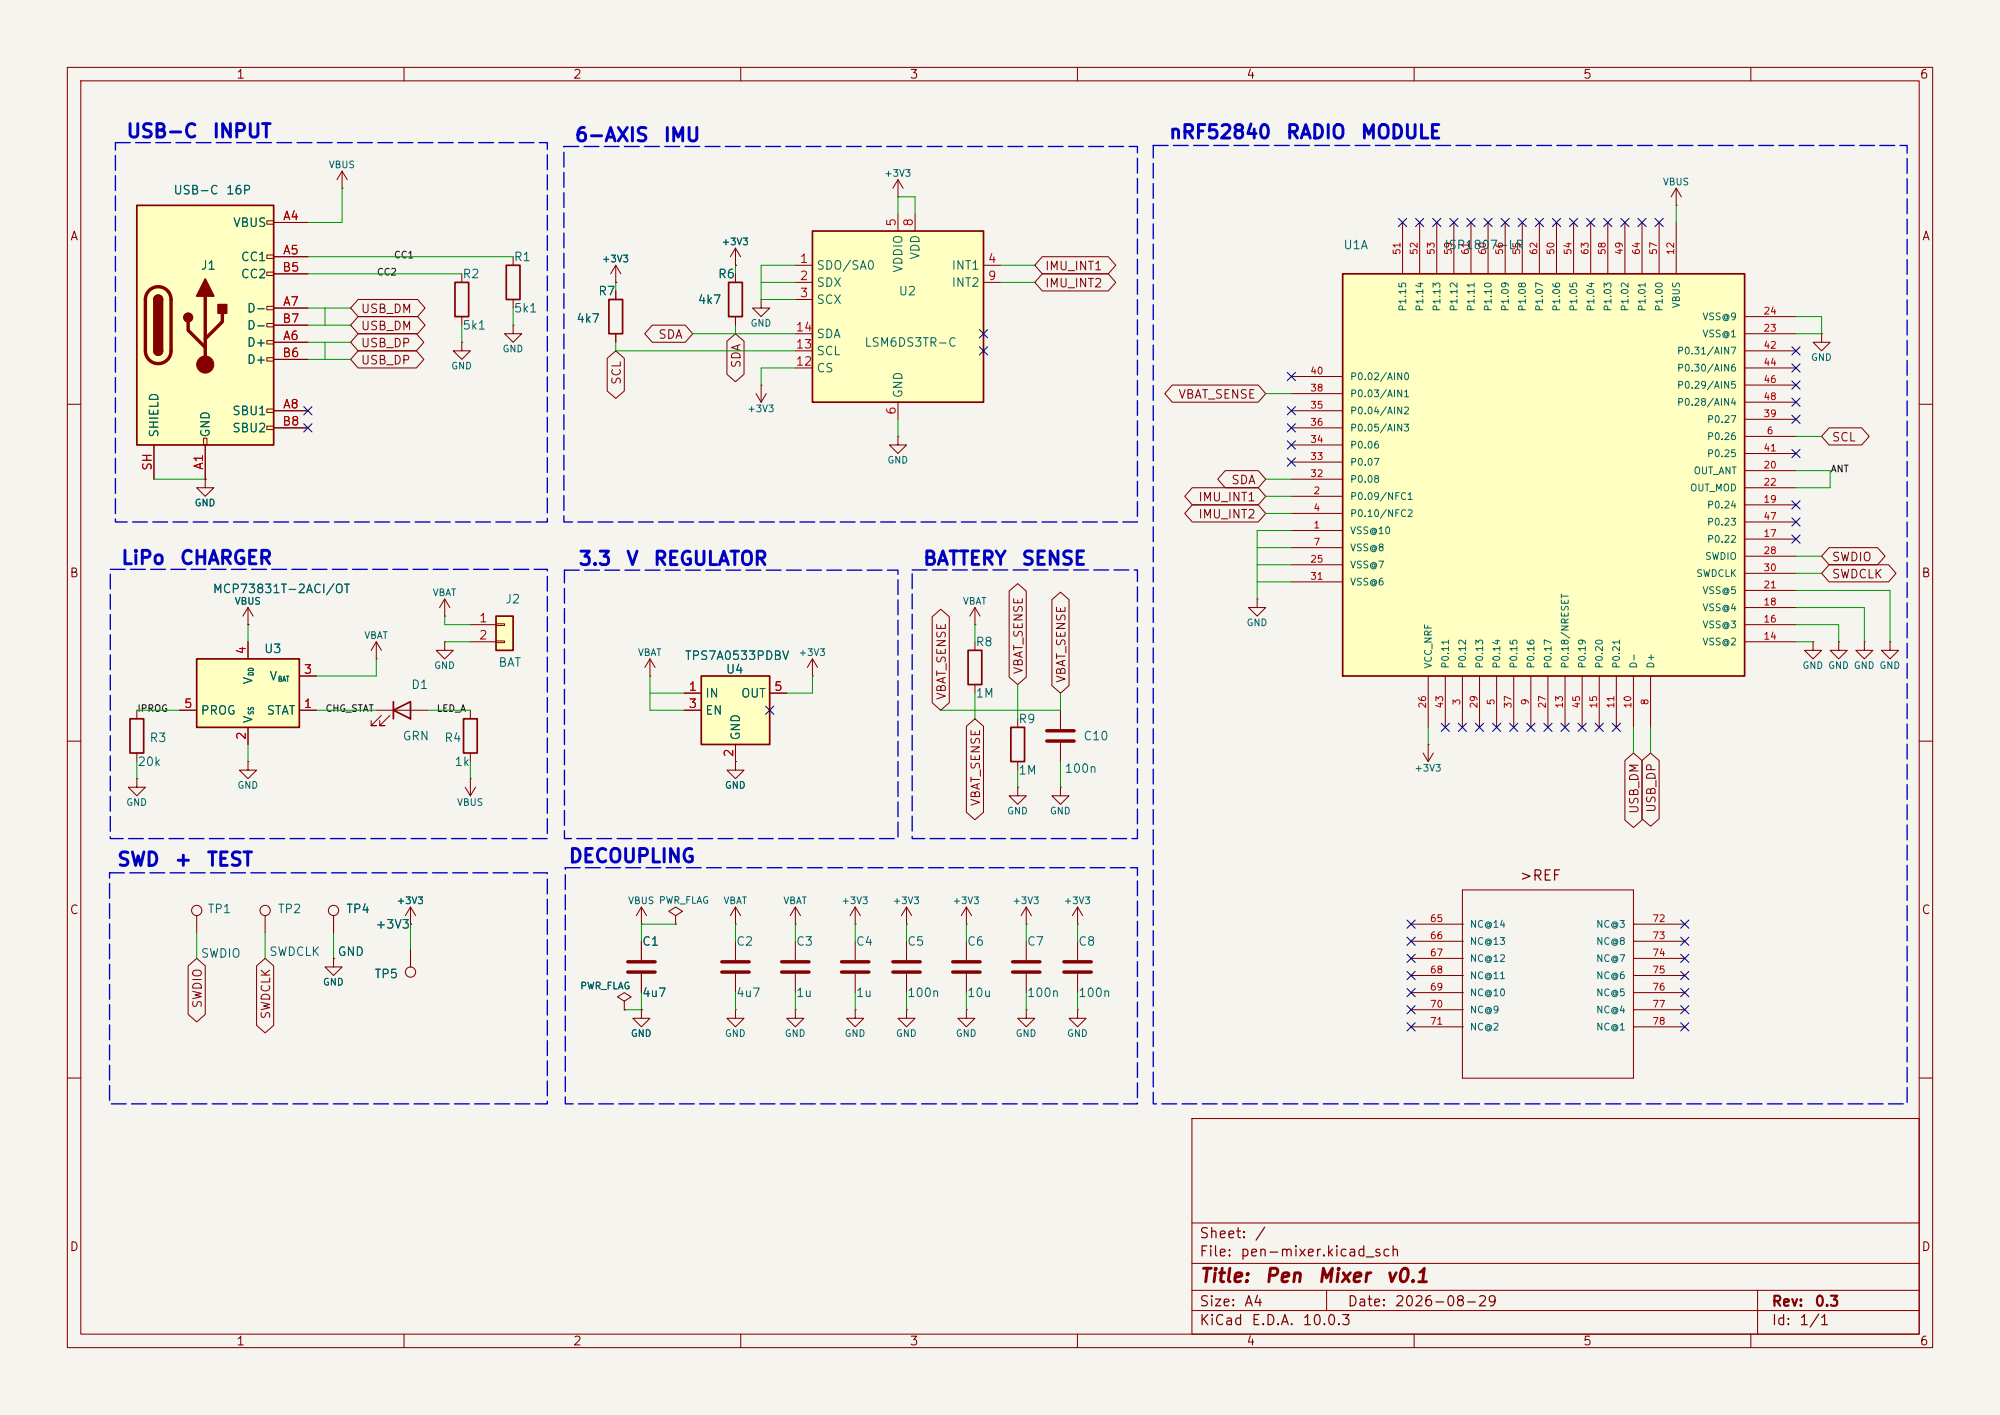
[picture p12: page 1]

Size: A4 | Rev: 0.3
KiCad E.D.A. 10.0.3 | Id: 1/1

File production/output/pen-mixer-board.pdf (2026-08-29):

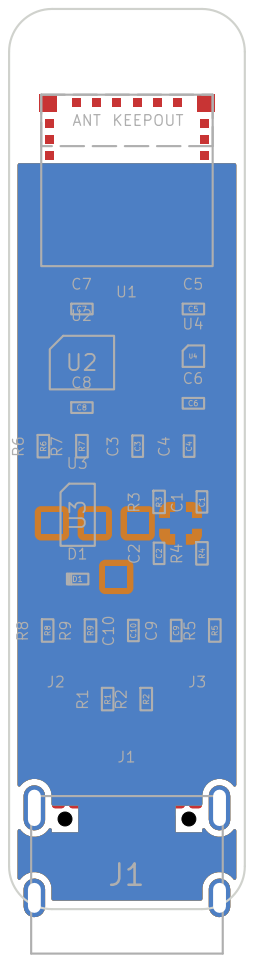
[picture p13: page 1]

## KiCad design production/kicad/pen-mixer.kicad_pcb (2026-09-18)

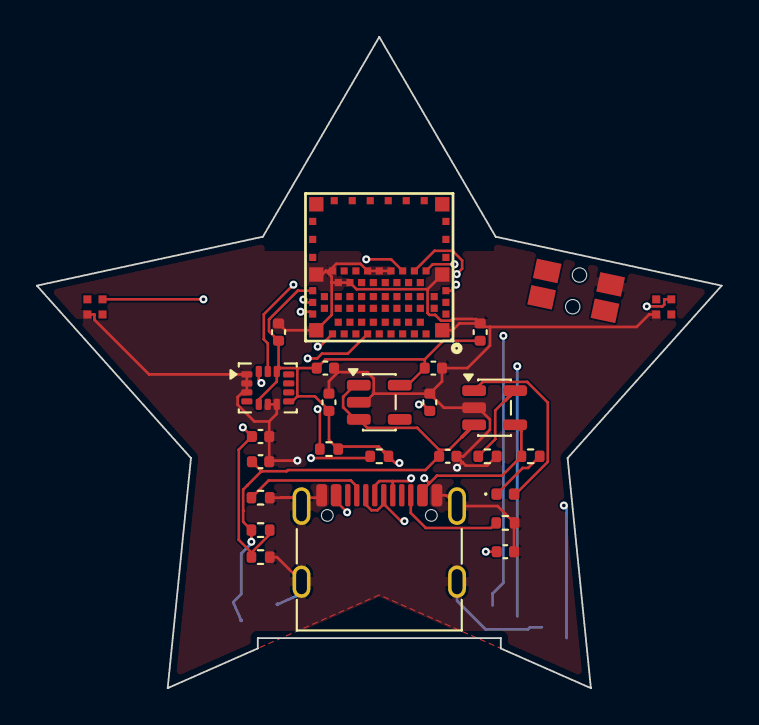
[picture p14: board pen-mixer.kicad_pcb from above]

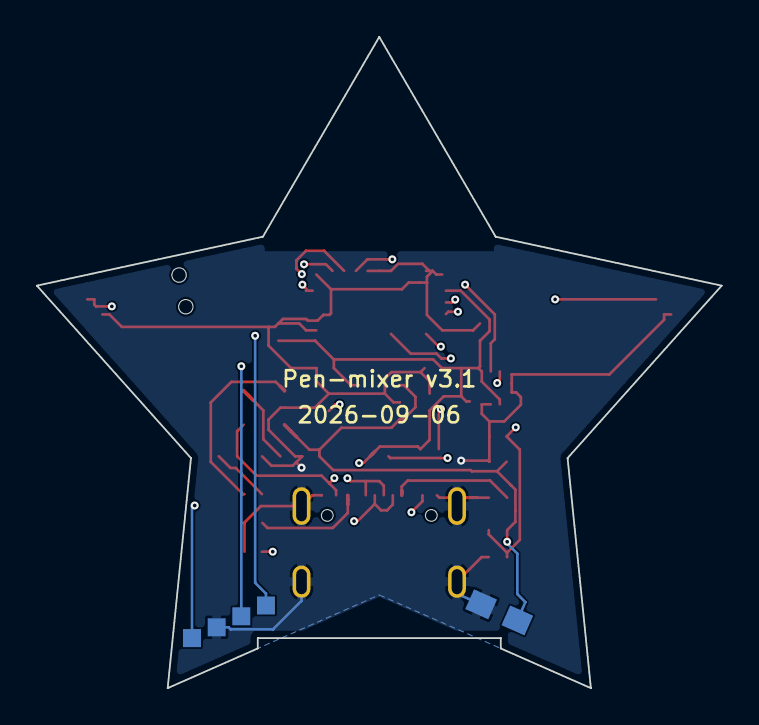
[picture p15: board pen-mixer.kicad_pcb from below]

Board: 4 copper layers, 38.0 x 36.2 mm, 32 parts (5 on the bottom side), 16 nets.

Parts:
C1, C2: 4u7; C_0402_1005Metric
C3, C4: 1u; C_0402_1005Metric
C5, C7, C8, C10, C11: 100n; C_0402_1005Metric
C6: 10u; C_0402_1005Metric
D1: GRN; LED_0402_1005Metric
J1: USB-C 16P; GT-USB-7010ASV
J2: BAT; SolderPad_1.2x2.0mm
LED1, LED2: XL-1010RGBC; LED-SMD_4P-L1.0-W1.0-TL_XL-1010RGBC-WS2812B
R1, R2: 5k1; R_0402_1005Metric
R3: 20k; R_0402_1005Metric
R4: 1k; R_0402_1005Metric
R6, R7: 4k7; R_0402_1005Metric
R8, R9: 1M; R_0402_1005Metric
SW1: EVQP7C01P; SW-SMD_EVQP7C01P
TP1: SWDIO; TestPad_1.0mm
TP2: SWDCLK; TestPad_1.0mm
TP4: GND; TestPad_1.0mm
TP5: +3V3; TestPad_1.0mm
U1: ISP1807-LR; BULETM-SMD_ISP1807
U2: LSM6DS3TR-C; LGA-14_3x2.5mm_P0.5mm_LayoutBorder3x4y
U3: MCP73831T-2ACI/OT; SOT-23-5
U4: TPS7A0533PDBV; SOT-23-5

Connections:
+3V3: C4.1, C5.1, C6.1, C7.1, C8.1, R6.2, R7.2, TP5.1, U1.26, U2.5, U2.8, U2.12, U4.5
CC1: J1.A5, R1.1
CC2: J1.B5, R2.1
CHG_STAT: D1.2, U3.1
GND: C1.2, C2.2, C3.2, C4.2, C5.2, C6.2, C7.2, C8.2, C10.2, C11.2, J1.A1, J1.A12, J1.B1, J1.B12, J1.SH, J2.2, LED1.3, LED2.3, R1.2, R2.2, R3.2, R9.2, SW1.2, TP4.1, U1.1, U1.7, U1.14, U1.16, U1.18, U1.21, U1.23, U1.24, U1.25, U1.31, U2.1, U2.2, U2.3, U2.6, U2.7, U3.2, U4.2
IPROG: R3.1, U3.5
LED_A: D1.1, R4.2
SCL: R7.1, U1.6, U2.13
SDA: R6.1, U1.32, U2.14
SWDCLK: TP2.1, U1.30
SWDIO: TP1.1, U1.28
USB_DM: J1.A7, J1.B7, U1.10
USB_DP: J1.A6, J1.B6, U1.8
VBAT: C2.1, C3.1, C11.1, J2.1, LED1.2, LED2.2, R8.1, U3.3, U4.1, U4.3
VBAT_SENSE: C10.1, R8.2, R9.1, U1.38
VBUS: C1.1, J1.A4, J1.A9, J1.B4, J1.B9, R4.1, U1.12, U3.4

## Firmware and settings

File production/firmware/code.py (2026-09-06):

# code.py - Pen Mixer v2.1 production board (ISP1807 / nRF52840 + LSM6DS3TR-C)
#
# UNTESTED: written against the v2.1 schematic before the board was assembled.
# Pin map from production/kicad/reference-nets.json and the ISP1807 symbol:
#     LED_DATA    P0.20  two chained 1x1 mm addressable RGB LEDs (LED1 battery, LED2 link)
#     BTN         P0.17  side tactile switch to GND, wake-capable
#     VBAT_SENSE  P0.03  AIN1, battery through R8/R9 = 1M/1M divider (VBAT = 2 x ADC)
#     SDA / SCL   P0.08 / P0.26  IMU I2C
#     IMU_INT1/2  P0.09 / P0.10  (NFC pins; unused here)
#
# Implements the PRD interface set on top of the motion stream:
#     I1  battery LED, four states: red <10%, orange 10-40%, green 40-80%, white >80%
#     I2  power button: press to turn on, press to turn off (System OFF sleep,
#         wake on the same button), long press to start Bluetooth pairing
#     I3  Bluetooth LED: solid blue when connected, flashing while pairing is ready
# and streams "tilt,roll,energy,sway" frames over a Nordic UART service, the
# same format as the prototype firmware, so the desktop app needs no changes.
#
# REQUIRES on CIRCUITPY/lib: adafruit_ble/, adafruit_lsm6ds/, adafruit_register/,
# adafruit_bus_device/, neopixel.mpy, adafruit_pixelbuf.mpy

import math
import time

import alarm
import analogio
import board  # noqa: F401 - kept for builds that expose board pins
import busio
import digitalio
import microcontroller
import neopixel
from adafruit_ble import BLERadio
from adafruit_ble.advertising.standard import ProvideServicesAdvertisement
from adafruit_ble.services.nordic import UARTService
from adafruit_lsm6ds.lsm6ds3trc import LSM6DS3TRC

PIN_LED_DATA = microcontroller.pin.P0_20
PIN_BTN = microcontroller.pin.P0_17
PIN_VBAT = microcontroller.pin.P0_03
PIN_SDA = microcontroller.pin.P0_08
PIN_SCL = microcontroller.pin.P0_26

G = 9.80665
FRAME_HZ = 100
LONG_PRESS_S = 1.5
DIVIDER = 2.0            # R8/R9 = 1M/1M
VBAT_EMPTY = 3.3         # LiPo considered 0% here
VBAT_FULL = 4.15         # and 100% here (charger terminates at 4.2)
BATTERY_POLL_S = 5.0
PAIR_BLINK_S = 0.25

# Colors as (r, g, b), kept dim: these are 1 x 1 mm LEDs behind a clear case.
RED = (40, 0, 0)
ORANGE = (40, 14, 0)
GREEN = (0, 40, 0)
WHITE = (30, 30, 30)
BLUE = (0, 0, 40)
OFF = (0, 0, 0)

pixels = neopixel.NeoPixel(PIN_LED_DATA, 2, brightness=1.0, auto_write=False)
LED_BATTERY, LED_LINK = 0, 1

button = digitalio.DigitalInOut(PIN_BTN)
button.switch_to_input(pull=digitalio.Pull.UP)

vbat_adc = analogio.AnalogIn(PIN_VBAT)


def battery_volts():
    return vbat_adc.value / 65535 * vbat_adc.reference_voltage * DIVIDER


def battery_percent():
    v = battery_volts()
    return max(0.0, min(100.0, (v - VBAT_EMPTY) / (VBAT_FULL - VBAT_EMPTY) * 100.0))


def battery_color(percent):
    if percent < 10:
        return RED
    if percent < 40:
        return ORANGE
    if percent < 80:
        return GREEN
    return WHITE


def show(battery=None, link=None):
    if battery is not None:
        pixels[LED_BATTERY] = battery
    if link is not None:
        pixels[LED_LINK] = link
    pixels.show()


def pressed():
    return not button.value


def power_off():
    """I2: press to turn off. Deep sleep until the button is pressed again."""
    show(OFF, OFF)
    time.sleep(0.3)
    while pressed():
        time.sleep(0.05)
    wake = alarm.pin.PinAlarm(pin=PIN_BTN, value=False, pull=True)
    alarm.exit_and_deep_sleep_until_alarms(wake)


def wait_release_and_classify():
    """Return "long" if held past LONG_PRESS_S, else "short"."""
    t0 = time.monotonic()
    while pressed():
        if time.monotonic() - t0 >= LONG_PRESS_S:
            return "long"
        time.sleep(0.02)
    return "short"


# IMU: same math as the prototype so the app sees identical frames.
i2c = busio.I2C(PIN_SCL, PIN_SDA)
imu = LSM6DS3TRC(i2c)

# Sway (PRD M2): leaky integral of the gyro rate about the sweep axis.
SWAY_AXIS = 2
SWAY_SCALE = 1.5
SWAY_LEAK = 0.97
sway = 0.0


def update_sway(gyro, dt):
    global sway
    sway = sway * SWAY_LEAK + gyro[SWAY_AXIS] * dt / SWAY_SCALE
    sway = max(-1.0, min(1.0, sway))
    return sway


def read_frame(dt):
    ax, ay, az = imu.acceleration
    tilt = math.degrees(math.atan2(ax, math.sqrt(ay * ay + az * az)))
    roll = math.degrees(math.atan2(ay, az))
    mag = math.sqrt(ax * ax + ay * ay + az * az)
    energy = min(1.0, abs(mag - G) / 8.0)
    return tilt, roll, energy, update_sway(imu.gyro, dt)


ble = BLERadio()
ble.name = "PenMixer-Lexy"
uart = UARTService()
advert = ProvideServicesAdvertisement(uart)
period = 1.0 / FRAME_HZ

# Boot (a button press woke us, or USB power arrived): show battery, start pairing.
show(battery=battery_color(battery_percent()), link=OFF)
pairing = True
ble.start_advertising(advert)
last_battery = time.monotonic()
last_blink = time.monotonic()
blink_on = False

while True:
    now = time.monotonic()

    # I1: battery LED, refreshed every few seconds.
    if now - last_battery >= BATTERY_POLL_S:
        show(battery=battery_color(battery_percent()))
        last_battery = now

    # I2: button. Short press turns off; long press (re)starts pairing.
    if pressed():
        kind = wait_release_and_classify()
        if kind == "long":
            if ble.connected:
                for conn in ble.connections:
                    conn.disconnect()
            if not ble.advertising:
                ble.start_advertising(advert)
            pairing = True
        else:
            power_off()

    # I3: link LED. Flashing while pairing is ready, solid blue when connected.
    if ble.connected:
        if pairing:
            ble.stop_advertising()
            pairing = False
            show(link=BLUE)
        tilt, roll, energy, sway_now = read_frame(period)
        try:
            uart.write(("%.2f,%.2f,%.3f,%.3f\n" % (tilt, roll, energy, sway_now)).encode())
        except Exception:
            pass
        time.sleep(period)
    else:
        if not pairing:
            # Link dropped: advertise again and go back to flashing.
            pairing = True
            ble.start_advertising(advert)
        if now - last_blink >= PAIR_BLINK_S:
            blink_on = not blink_on
            show(link=BLUE if blink_on else OFF)
            last_blink = now
        time.sleep(0.02)

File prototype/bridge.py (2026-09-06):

#!/usr/bin/env python3
"""Pen Mixer bridge: USB serial -> smoothing -> UDP to Pure Data.

Reads "tilt,roll,energy" frames from the board, smooths them, maps them to
audio parameters, and sends them to Pd as FUDI messages (plain text over UDP,
so Pd needs no OSC externals).

    python3 bridge.py               # autodetect the serial port
    python3 bridge.py --port /dev/tty.usbmodem14201
    python3 bridge.py --quiet       # no console meter
"""

import argparse
import glob
import math
import os
import re
import select
import socket
import subprocess
import sys
import time

try:
    import serial            # optional; a raw fallback is used if absent
except ImportError:
    serial = None

# CircuitPython prints an ANSI terminal-title sequence on boot, which lands in
# the middle of the first data frame.  Strip all escapes, not just that one.
ANSI = re.compile(r"\x1b\][^\x07\x1b]*(?:\x07|\x1b\\)|\x1b\[[0-9;]*[A-Za-z]")

PD_ADDR = ("127.0.0.1", 9999)
BAUD = 115200

try:
    import dashboard
except ImportError:
    dashboard = None


def find_port():
    for pattern in ("/dev/cu.usbmodem*", "/dev/ttyACM*", "/dev/cu.usbserial*"):
        hits = sorted(glob.glob(pattern))
        if hits:
            return hits[0]
    return None


class RawSerial:
    """Minimal line reader so the bridge runs with no third-party packages.

    pyserial is nicer and cross-platform, but on macOS and Linux reading the
    tty directly is enough and removes the only install step.
    """

    def __init__(self, port, baud):
        subprocess.run(["stty", "-f", port, str(baud), "raw", "-echo"],
                       check=False, capture_output=True)
        self.fd = os.open(port, os.O_RDONLY | os.O_NONBLOCK)
        self.buf = b""

    def readline(self):
        while b"\n" not in self.buf:
            r, _, _ = select.select([self.fd], [], [], 1.0)
            if not r:
                return b""
            try:
                chunk = os.read(self.fd, 4096)
            except BlockingIOError:
                return b""
            if not chunk:
                return b""
            self.buf += chunk
        line, self.buf = self.buf.split(b"\n", 1)
        return line

    def close(self):
        os.close(self.fd)


class Smooth:
    """One-pole exponential smoother.

    Raw sensor values fed straight into a filter cutoff produce clicks and
    zipper noise.  This is the single most important few lines in the file.
    """

    def __init__(self, alpha=0.4):
        self.alpha = alpha
        self.y = None

    def __call__(self, x):
        self.y = x if self.y is None else self.y + self.alpha * (x - self.y)
        return self.y


def clamp(v, lo, hi):
    return lo if v < lo else hi if v > hi else v


def linexp(v, in_lo, in_hi, out_lo, out_hi):
    """Linear input -> exponential output. Pitch and frequency are perceived
    logarithmically, so a linear cutoff sweep sounds wrong."""
    f = clamp((v - in_lo) / (in_hi - in_lo), 0.0, 1.0)
    return out_lo * math.pow(out_hi / out_lo, f)


def linlin(v, in_lo, in_hi, out_lo, out_hi):
    f = clamp((v - in_lo) / (in_hi - in_lo), 0.0, 1.0)
    return out_lo + f * (out_hi - out_lo)


def meter(label, value, lo, hi, width=22):
    f = clamp((value - lo) / (hi - lo), 0.0, 1.0)
    filled = int(f * width)
    return "%-7s [%s%s]" % (label, "#" * filled, "-" * (width - filled))


def main():
    ap = argparse.ArgumentParser()
    ap.add_argument("--port", default=None, help="serial device")
    ap.add_argument("--alpha", type=float, default=0.4,
                    help="smoothing 0.05 (heavy/laggy) .. 1.0 (raw/clicky). "
                         "Measured at 250 Hz: 0.05=236ms, 0.15=76ms, 0.4=24ms, "
                         "0.5=20ms to settle. Budget is ~15ms end to end.")
    ap.add_argument("--quiet", action="store_true")
    ap.add_argument("--web", type=int, default=8080,
                    help="port for the live dashboard, 0 to disable")
    ap.add_argument("--ble", action="store_true",
                    help="read over Bluetooth LE instead of USB serial "
                         "(board must be running code_ble.py)")
    args = ap.parse_args()

    if dashboard and args.web:
        dashboard.serve(args.web)
        print("dashboard: http://localhost:%d" % args.web)

    if args.ble:
        return run_ble(args)

    port = args.port or find_port()
    if not port:
        sys.exit("No serial port found. Plug the board in, or pass --port.")

    try:
        ser = serial.Serial(port, BAUD, timeout=1) if serial else RawSerial(port, BAUD)
    except Exception as e:
        sys.exit("Could not open %s: %s" % (port, e))

    sock = socket.socket(socket.AF_INET, socket.SOCK_DGRAM)
    s_tilt, s_roll, s_energy = (Smooth(args.alpha) for _ in range(3))

    print("bridge: %s (%s) -> udp %s:%d   (ctrl-c to stop)" % (
        port, "pyserial" if serial else "raw", PD_ADDR[0], PD_ADDR[1]))
    frames = 0
    last_print = 0.0
    bad = 0
    t_start = time.monotonic()

    try:
        while True:
            raw = ser.readline().decode("utf-8", "ignore")
            raw = ANSI.sub("", raw).strip()
            if not raw:
                continue
            parts = raw.split(",")
            if len(parts) != 3:
                bad += 1
                continue
            try:
                tilt, roll, energy = (float(p) for p in parts)
            except ValueError:
                bad += 1
                continue

            tilt = s_tilt(tilt)
            roll = s_roll(roll)
            energy = s_energy(energy)

            # --- the mapping.  This is the part worth arguing about. ---
            cutoff = linexp(tilt, -45.0, 45.0, 80.0, 12000.0)   # tilt  -> filter
            gain = linlin(roll, -90.0, 90.0, 0.25, 1.75)        # twist -> level
            wet = linlin(energy, 0.0, 1.0, 0.0, 1.0)            # speed -> send

            for name, val in (("cutoff", cutoff), ("gain", gain), ("wet", wet)):
                sock.sendto(("%s %.4f;\n" % (name, val)).encode(), PD_ADDR)

            frames += 1
            now = time.monotonic()

            if dashboard:
                dashboard.publish(tilt=tilt, roll=roll, energy=energy,
                                  cutoff=cutoff, gain=gain, wet=wet,
                                  fps=int(frames / max(0.001, now - t_start)),
                                  bad=bad, mode="usb")
            if not args.quiet and now - last_print > 0.05:
                last_print = now
                sys.stdout.write("\r%s  %s   %5d fps  %d bad " % (
                    meter("cutoff", cutoff, 80, 12000),
                    meter("gain", gain, 0.25, 1.75),
                    frames, bad))
                sys.stdout.flush()
    except KeyboardInterrupt:
        print("\nstopped after %d frames (%d malformed)" % (frames, bad))
    finally:
        ser.close()
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

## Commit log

2026-08-29 add complete project
    Claude-Session: https://claude.ai/code/session_01RCYT2QSY7BVZDeTyE9KrC4
    [bom.csv, pen-mixer.kicad_pcb, pen-mixer.kicad_sch]
2026-08-29 route board add module frames
    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
    [bom.csv, pen-mixer.kicad_pcb, pen-mixer.kicad_sch]
2026-08-29 wires in modules globals between
    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
    [pen-mixer.kicad_sch]
2026-08-29 arrange modules remove pours
    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
    [pen-mixer.kicad_pcb, pen-mixer.kicad_sch]
2026-08-29 ground usb shield pads
    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
    [pen-mixer.kicad_pcb]
2026-08-29 vendor footprint full track routing
    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
    [pen-mixer.kicad_pcb]
2026-08-29 stock symbols full route zero unrouted
    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
    [bom.csv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]
2026-08-29 user layout radio module tidy
    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
    [pen-mixer.kicad_sch]
2026-08-29 clean dangling scraps
    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
    [pen-mixer.kicad_sch]
2026-08-29 remove last stub
    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
    [pen-mixer.kicad_sch]
2026-08-29 remake radio module
    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
    [pen-mixer.kicad_sch]
2026-08-29 add lcsc part numbers
    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
    [bom.csv, pen-mixer.kicad_sch]
2026-08-29 resize radio symbol body
    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
    [pen-mixer.kicad_sch]
2026-08-29 repair user compaction connectivity
    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
    [pen-mixer.kicad_sch]
2026-08-29 radio symbol 60mm t-split normalize
    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
    [pen-mixer.kicad_sch]
2026-08-29 label based connectivity for fragile nets
    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
    [pen-mixer.kicad_sch]
2026-08-29 remove fsr rearrange back pads
    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
    [pen-mixer.kicad_pcb, pen-mixer.kicad_sch]
2026-08-29 swap tp and battery pad ends
    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
    [pen-mixer.kicad_pcb]
2026-08-29 nudge tp1 clear of via
    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
    [pen-mixer.kicad_pcb]
2026-08-29 pads to board extremes
    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
    [pen-mixer.kicad_pcb, pen-mixer.kicad_sch]
2026-08-29 test pads to board tip
    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
    [pen-mixer.kicad_pcb]
2026-08-29 route complete zero unrouted
    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
    [pen-mixer.kicad_pcb]
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2026-08-29 board fully routed verified
    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
    [pen-mixer-B_Courtyard.gbr, pen-mixer-B_Cu.gbl, pen-mixer-B_Fab.gbr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]
2026-08-29 unroute board
    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
    [pen-mixer.kicad_pcb]
2026-08-29 clean full reroute zero violations
    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
    [pen-mixer-B_Courtyard.gbr, pen-mixer-B_Cu.gbl, pen-mixer-B_Fab.gbr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]
2026-08-29 fix wire tee gaps
    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
    [pen-mixer.kicad_pcb, pen-mixer.kicad_sch]
2026-08-29 silkscreen designators
    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
    [pen-mixer.kicad_pcb]
2026-08-29 halve designator size
    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
    [pen-mixer.kicad_pcb]
2026-08-29 designator stroke fix
    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
    [pen-mixer.kicad_pcb]
2026-08-29 board label and date
    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
    [pen-mixer.kicad_pcb]
2026-08-29 designators to 0.8mm
    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
    [pen-mixer.kicad_pcb]
2026-08-29 hide component designators
    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
    [pen-mixer.kicad_pcb]
2026-08-29 add gnd copper zones
    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
    [pen-mixer.kicad_pcb]
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2026-08-30 add excel boms
    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
    [bom-production.xlsx, bom-prototype.xlsx, bom.csv]
2026-08-30 source boms by vendor
    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
    [bom-production.xlsx, bom-prototype.xlsx]
2026-08-30 drop mount from bom
    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
    [bom-prototype.xlsx]
2026-08-30 add production prices
    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
    [bom-production.xlsx]
2026-08-30 redhat styled boms
    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
    [bom-production.xlsx, bom-prototype.xlsx, bom.csv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]
2026-08-30 remove row banding
    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
    [bom-production.xlsx, bom-prototype.xlsx]
2026-08-30 fix schematic wire export
    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
    [pen-mixer.kicad_sch]
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2026-08-30 Revert "schematic image as png"
    This reverts commit 5a036b454c12c1473d9fbf029c451c3cc2b12c59.
2026-08-30 attach isp1807 3d model
    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
    [pen-mixer.kicad_pcb]
2026-08-30 attach usb-c 3d model
    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
    [pen-mixer.kicad_pcb]
2026-08-30 jlc 3d models
    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
    [pen-mixer.kicad_pcb]
2026-08-30 official jlc footprint
    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
    [pen-mixer.kicad_pcb, pen-mixer.kicad_sch]
2026-08-30 fix stale footprint note
    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
2026-08-30 blender render scenes
    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
    [pen-mixer.blend]
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2026-08-30 board v2 13x35
    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
    [pen-mixer.kicad_pcb, pen-mixer.kicad_sch]
2026-08-30 organize kicad folder
    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
    [pen-mixer.kicad_pcb, pen-mixer.kicad_sch]
2026-08-30 battery pads at tip
    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
    [pen-mixer.kicad_pcb, pen-mixer.kicad_sch]
2026-08-30 restore battery routes
    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
    [pen-mixer.kicad_pcb]
2026-08-30 add v21 hardware
    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
    [bom.csv, pen-mixer.kicad_pcb, pen-mixer.kicad_sch]
2026-08-30 v21 blender scene
    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
    [pen-mixer.blend]
2026-08-30 fix board thickness
    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
    [pen-mixer.blend, pen-mixer.kicad_pcb]
2026-08-30 thin board glowing leds
    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
    [pen-mixer.blend]
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2026-09-06 fix ble mode startup
    [bridge.py]
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2026-09-06 remove touch rig remnants
    Pen is the instrument: motion meters (tilt, twist) replace the pad
    meters, Pen control replaces Touch control, one signed mapping for every
    source, simulator sweeps signed motion, MotionFrame naming.
    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
    [frames.py, mapping.py, serialio.py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]
2026-09-06 add sway axis for mids
    Firmware streams a fourth value, sway, a leaky gyro integral of
    horizontal motion (-1..1). The app parses 3- or 4-field frames, maps
    sway to the mid band (left cuts, right boosts, PRD M2), shows a Sway
    meter, and the simulator sweeps it.
    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
    [code.py, code_ble.py, frames.py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]
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2026-09-06 add case print files
    Case top and bottom exported from the Blender model as millimetre STLs
    with order notes (PRD P2), and the battery soak test script that logs
    BLE streaming runtime on one charge (PRD P4).
    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
    [case_bottom.stl, case_top.stl]
2026-09-06 free nfc pins from imu
    Disconnect IMU_INT1/INT2 from U1 P0.09/P0.10 (NFC1/NFC2) so the NFC
    antenna can use them; the firmware polls the IMU and never used the
    interrupts. Schematic: 4 wires and 4 labels removed, no-connect flags on
    U1 pins 2, 4 and U2 INT1, INT2. PCB: 24 tracks and vias and 4 pad nets
    removed. DRC 0 violations, 0 unconnected; ERC unchanged; netlist matches
    reference-nets.json after the four intended removals.
    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
    [pen-mixer.kicad_pcb, pen-mixer.kicad_sch]
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2026-09-06 freeze v2 board
    Copy of the v2.1 KiCad project (13 x 35 mm bar) into production/kicad/v2,
    tagged v2, before the v3 star redesign.
    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
    [pen-mixer.kicad_pcb, pen-mixer.kicad_sch]
2026-09-06 add v3 star board
    Regular five-point star, 40 mm tip to tip, antenna at the top prong with
    its copper keep-out, all v2.1 parts kept. J1 becomes a vertical top-entry
    USB-C (G-Switch GT-USB-7055E, C7450622, footprint and 3D model via
    easyeda2kicad) so every prong stays identical; schematic netlist is
    IDENTICAL to reference-nets.json. Routed with freerouting (0 unrouted),
    GND pours on all four layers refilled, DRC 0 errors and 0 unconnected
    with only the two accepted label text-thickness warnings, schematic
    parity clean. U3 pad 2 connects solid to the pour (no room for two
    thermal spokes). Renders in production/output/v3.
    Claude-Session: https://claude.ai/code/session_01Q1V828NK1ouT6YXKEbiFUx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
    [bom.csv, pen-mixer.kicad_pcb, pen-mixer.kicad_sch]
2026-09-06 fix low output volume
    [app.py, audio.py, spectrum.py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]
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2026-09-17 revise v3 star board
    Flat side-entry USB-C recessed in the bottom notch, power button parallel
    to the right arm's edge, LEDs mirrored left and right, test and battery
    pads in lines parallel to the leg edges, passives aligned, rerouted with
    freerouting (28 vias, was 34). Netlist identical to reference-nets.json;
    DRC 0 errors, 0 unconnected.
    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
    [bom.csv, pen-mixer.kicad_pcb, pen-mixer.kicad_sch]
2026-09-25 add prototype case
    Two-part snap-fit box for the XIAO prototype, 58 x 25 x 15 mm inside,
    3 mm rounded corners, with slide rails on the lid for a 58 x 25 x 4 mm
    wooden slab. Lip-and-bump snap, USB-C opening on one end. Generated by
    production/blender/case_proto.py; case_proto_both.stl is the print bed
    layout.
    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
    [case_proto.blend, case_proto_both.stl, case_proto_bottom.stl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]
2026-09-26 add star case
    Snap-fit case with star cut-outs and slide rails for a 58 x 27 x 5 mm
    wooden slab, sliced for transparent PLA on the Mega S.
    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
    [bottom.stl, case_both.blend, enclosure.scad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]
2026-09-27 split slab rails off lid
    The star roof printed as a 27 mm unsupported bridge between the rails and
    failed. The rails are now a separate glue-on frame, so the lid prints
    roof-down flat on the bed and nothing bridges.
    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
    [case_both.blend, enclosure.scad, rails.stl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]
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2026-09-27 rejoin rails to lid
    Rails are part of the lid again; the channel under the roof gets support
    material instead of an unsupported bridge. Adds a 5 mm brim and a 65 C bed.
    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
    [case_both.blend, enclosure.scad, rails.stl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]
2026-09-27 widen slab channel
    Channel grows 2 mm wider and 1 mm taller after the slab did not fit;
    lips lengthened to keep their grip, rail edges rounded.
    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
    [case_both.blend, enclosure.scad, stars.3mf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]
2026-09-28 Updated UI button positioning, shadowing, disk, fixed audio input/output issue
    [app.py, audio.py, code.py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]
